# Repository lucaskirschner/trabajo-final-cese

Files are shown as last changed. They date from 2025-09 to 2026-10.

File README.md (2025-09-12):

# \# Trabajo Final CESE – \[Título del Proyecto]

# 

# \## Objetivo

# Breve descripción del sistema (HW+FW) y casos de uso.

# 

# \## Estructura

# \- `hardware/`: Altium, libs, outputs, mecánica.

# \- `firmware/`: drivers, app, tests, build.

# \- `docs/`: requisitos, arquitectura, plan, API.

# 

# \## Cómo compilar (FW)

# Requisitos, comando (CMake/Make), cómo flashear.

# 

# \## Paquetes de fabricación (HW)

# Ubicación y cómo generarlos/validarlos.

# 

# \## Versionado

# Tags `vX.Y.Z-hwA#`. Ver `CHANGELOG.md`.

# 

# \## Licencia

# MIT (o la que definas).

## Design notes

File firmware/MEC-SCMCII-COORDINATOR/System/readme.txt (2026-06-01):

===============================================================================
SYSTEM
===============================================================================

Esta carpeta contiene la arquitectura principal del firmware de la plataforma
embebida. Su organización se basa en una estructura modular por capas, con el
objetivo de facilitar la reutilización de código, el mantenimiento, la
escalabilidad y la adaptación del sistema a distintos escenarios de
automatización industrial.

===============================================================================
APP/
===============================================================================

Contiene la lógica de aplicación del sistema.

En esta capa se implementa el comportamiento funcional de cada tipo de estación
(central o remota), así como también la lógica personalizada desarrollada por
el usuario final. Aquí se integran los distintos servicios y drivers del sistema
para construir la funcionalidad completa de la aplicación.

Esta carpeta puede incluir:

- Aplicación de estación central.
- Aplicación de estación remota.
- Lógica de usuario.
- Máquinas de estados.
- Algoritmos de control.
- Procesamiento de datos.

La capa APP no debería acceder directamente al hardware, sino utilizar las APIs
provistas por las capas inferiores.

===============================================================================
BSP/  (Board Support Package)
===============================================================================

Contiene la capa de abstracción del hardware de la placa.

Su función es desacoplar el firmware de los detalles específicos del hardware
utilizado, encapsulando el acceso a periféricos, GPIOs y recursos físicos de la
plataforma.

Esta carpeta puede incluir:

- Configuración de GPIO.
- Manejo de LEDs.
- Lectura de botones.
- Control de señales de habilitación.
- Mapeo de pines.
- Inicialización básica de periféricos.

El objetivo es permitir la migración del firmware entre distintas revisiones de
hardware o placas minimizando modificaciones en las capas superiores.

===============================================================================
CONFIG/
===============================================================================

Contiene los archivos globales de configuración del sistema.

Aquí se centralizan parámetros de compilación, habilitación de módulos,
selección de funcionalidades y definiciones generales utilizadas por múltiples
capas del firmware.

Esta carpeta puede incluir:

- Configuración de estación central/remota.
- Selección de módulos habilitados.
- Parámetros del sistema.
- Definiciones globales.
- Configuración de hardware.
- Configuración de red y comunicación.

El objetivo es facilitar la parametrización del sistema desde un único punto.

===============================================================================
DRIVERS/
===============================================================================

Contiene los controladores de dispositivos y periféricos externos.

Esta capa encapsula la lógica de comunicación y control de los distintos
componentes conectados al microcontrolador, proporcionando APIs reutilizables e
independientes de la aplicación.

Esta carpeta puede incluir:

- Drivers SPI/I2C/UART.
- Drivers de módulos inalámbricos.
- Drivers Ethernet.
- Drivers de entradas y salidas industriales.
- Drivers de sensores.
- Drivers de RTC.
- Drivers de expansores externos.

La capa DRIVERS debe enfocarse únicamente en el manejo funcional del
dispositivo, evitando incluir lógica de aplicación.

===============================================================================
RTOS/
===============================================================================

Contiene la estructura relacionada con el sistema operativo en tiempo real.

Aquí se organiza la creación y administración de tareas, colas, semáforos,
mutexes, timers y demás recursos asociados al RTOS utilizado por el sistema.

Esta carpeta puede incluir:

- Definición de tareas.
- Inicialización del scheduler.
- Gestión de colas y eventos.
- Configuración de prioridades.
- Temporizadores de software.
- Hooks del RTOS.

El objetivo es mantener centralizada toda la infraestructura de concurrencia y
sincronización del sistema.

===============================================================================
SERVICES/
===============================================================================

Contiene módulos de servicios reutilizables de alto nivel.

Estos módulos implementan funcionalidades generales utilizadas por la aplicación
y los distintos subsistemas del firmware, actuando como intermediarios entre los
drivers y la lógica de aplicación.

Esta carpeta puede incluir:

- Gestión de comunicación.
- Gestión de eventos.
- Servicios de temporización.
- Watchdog lógico.
- Diagnóstico y monitoreo.
- Manejo de errores.
- Registro de eventos y logs.
- Gestión de estados del sistema.

La capa SERVICES permite desacoplar la lógica de aplicación de detalles
específicos de implementación y promueve una arquitectura más modular y
escalable.

===============================================================================

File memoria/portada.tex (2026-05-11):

%----------------------------------------------------------------------------------------
% PORTADA
%----------------------------------------------------------------------------------------
\begin{titlepage}
    % Fondo completo con el PDF que incluye la barra y el logo
    \AddToShipoutPictureBG*{}

    % Contenido principal
    \begin{flushright}
        \setlength{\rightskip}{-2cm} % Ajusta la sangría derecha
        \vspace*{5cm} % Ajustar según la posición vertical deseada

        % Título
        {\fontfamily{phv}\bfseries\fontsize{33pt}{40pt}\selectfont
        Sistema modular para monitoreo y control industrial con comunicación inalámbrica y capacidades de automatización embebida} \\[1.5cm]

        % Autor
        {\fontfamily{phv}\fontsize{20pt}{25pt}\selectfont
        Ing. Lucas Sebastián Kirschner} \\[1cm]

        % Carrera o Maestría (comentar o descomentar la línea correspondiente)
        {\fontfamily{phv}\fontsize{15pt}{20pt}\selectfont
        \textbf{Carrera de Especialización en Sistemas Embebidos}
        % \textbf{Carrera de Especialización en Internet de las Cosas} \\
        % \textbf{Carrera de Especialización en Inteligencia Artificial} \\
        % \textbf{Maestría en Sistemas Embebidos} \\
        % \textbf{Maestría en Internet de las Cosas} \\
        % \textbf{Maestría en Inteligencia Artificial Embebida} \\
        % \textbf{Maestría en Computación de Borde} \\
        % \textbf{Maestría en Inteligencia Artificial} \\
        } \\[2cm]

        % Director
        {\fontfamily{phv}\fontsize{11pt}{15pt}\selectfont
        \textbf{Director:} Mg. Ing. Guillermo Alfredo Fernández (UNaM)} \\[1cm]

        % Jurados
        {\fontfamily{phv}\fontsize{11pt}{15pt}\selectfont
        \textbf{Jurados:}} \\[0.5cm]
        {\fontfamily{phv}\fontsize{11pt}{15pt}\selectfont
        Jurado 1 (pertenencia)} \\ 
        {\fontfamily{phv}\fontsize{11pt}{15pt}\selectfont
        Jurado 2 (pertenencia)} \\ 
        {\fontfamily{phv}\fontsize{11pt}{15pt}\selectfont
        Jurado 3 (pertenencia)} \\[2cm]

        % Fecha y lugar
        {\fontfamily{phv}\itshape\fontsize{10pt}{12pt}\selectfont
        Ciudad de Salto Encantado, octubre de 2026} % Ejemplo: Ciudad de Córdoba, junio de 2025
    \end{flushright}
\end{titlepage}

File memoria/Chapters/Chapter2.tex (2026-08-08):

\chapter{Introducción específica}
\label{Chapter2}

En este capítulo se describen las principales plataformas de hardware, componentes externos, capas de software y protocolos de comunicación utilizados durante el desarrollo del trabajo. Asimismo, se presentan las tecnologías de terceros empleadas para la implementación de las funciones de adquisición, procesamiento y comunicación del sistema.

%----------------------------------------------------------------------------------------

\section{Plataforma de hardware}

Tanto la estación central como las estaciones remotas del sistema utilizan el microcontrolador STM32H563RI de STMicroelectronics, perteneciente a la familia STM32H5 \cite{STM32H563,STMicroelectronics,STM32H5}. Esta decisión permitió uniformar la arquitectura de hardware y simplificar el desarrollo y mantenimiento del firmware. Además, facilitó la reutilización de controladores, configuraciones de periféricos y capas de abstracción de hardware entre ambos tipos de nodos.

El STM32H563RI se basa en una arquitectura ARM Cortex-M33 de 32 bits \cite{CortexM33}, orientada a sistemas embebidos de alto rendimiento y plataformas conectadas. El núcleo incorpora una unidad de punto flotante FPU (\textit{Floating Point Unit}, unidad de punto flotante), extensiones DSP (\textit{Digital Signal Processing}, procesamiento digital de señales) y mecanismos de seguridad basados en TrustZone \cite{STM32H5,STM32H563_RefManual}, adecuados para aplicaciones industriales e IoT.

El microcontrolador dispone de memoria Flash integrada y memoria SRAM (\textit{Static Random Access Memory}, memoria estática de acceso aleatorio) interna, además de una amplia variedad de periféricos de comunicación y control \cite{STM32H563}. Entre los periféricos utilizados durante el desarrollo se encuentran interfaces SPI (\textit{Serial Peripheral Interface}, interfaz periférica serie), UART (\textit{Universal Asynchronous Receiver-Transmitter}, transmisor-receptor asíncrono universal) y Ethernet MAC (\textit{Media Access Control}, control de acceso al medio).

La selección de este microcontrolador también se fundamentó en la disponibilidad de herramientas de desarrollo y middleware provistos por STMicroelectronics, incluido STM32CubeIDE \cite{stm32cubeide}, bibliotecas HAL (\textit{Hardware Abstraction Layer}, capa de abstracción de hardware) \cite{hal} y soporte para sistemas operativos de tiempo real como FreeRTOS \cite{freertos}. Estas herramientas simplificaron significativamente el desarrollo, depuración y mantenimiento del firmware del sistema.

%----------------------------------------------------------------------------------------

\section{Componentes y módulos externos}

Complementariamente a la plataforma de procesamiento basada en el STM32H\-563RI, el sistema incorpora diversos circuitos integrados y módulos externos destinados a la adquisición de señales industriales, el control de entradas y salidas, las comunicaciones cableadas e inalámbricas, la alimentación del sistema y la validación del firmware durante las etapas de desarrollo. A continuación, se describen los componentes más relevantes utilizados en el presente trabajo.

\subsection{SCLT3-8BT8}

El SCLT3-8BT8 de STMicroelectronics es una interfaz de entradas digitales industriales de ocho canales con transferencia serializada de estados mediante interfaz SPI \cite{sclt38bt8}. El dispositivo está orientado a aplicaciones de automatización industrial y PLC. Además, proporciona adaptación y protección para señales de 24 V provenientes de sensores y dispositivos industriales.

El circuito incorpora protección contra sobretensiones y compatibilidad con estándares industriales de inmunidad electromagnética, incluida IEC61000-4-2, IEC\-61000-4-4 e IEC61000-4-5. Además, dispone de indicadores de estado integrados y mecanismos de diagnóstico para detección de fallas en las entradas.

\subsection{VNI8200XP-32}

El VNI8200XP-32 de STMicroelectronics es un controlador de salidas digitales industriales de ocho canales basado en transistores MOSFET (\textit{Metal-Oxide-Semicon\-ductor Field-Effect Transistor}, transistor de efecto de campo metal-óxido-semicon\-ductor) de tipo \textit{high-side} \cite{vni8200xp32}. El dispositivo permite accionar cargas industriales de 24 V mediante una interfaz SPI o paralelo configurable.

El componente incorpora funciones de protección y diagnóstico, incluyendo protección térmica, limitación de corriente, detección de sobrecorriente, monitoreo de alimentación y señalización de fallas. También dispone de mecanismos específicos frente a condiciones de cortocircuito y sobretemperatura, características relevantes en aplicaciones industriales.

\subsection{SN65HVD82}

El SN65HVD82 de Texas Instruments es un transceptor RS-485 (\textit{Recommended Standard 485}) diseñado para comunicaciones industriales robustas \cite{sn65hvd82}. El dispositivo opera con alimentación de 5 V y proporciona transmisión diferencial compatible con buses multipunto de larga distancia.

El componente incorpora protección ESD (\textit{Electrostatic Discharge}, descarga electrostática) conforme a normas IEC orientadas a aplicaciones industriales y permite operación en entornos con elevado nivel de ruido electromagnético. Además, soporta altas velocidades de transmisión y presenta bajo consumo energético.

\subsection{MRF24J40}

El MRF24J40 de Microchip es un transceptor inalámbrico compatible con el estándar IEEE 802.15.4 \cite{mrf24j40}. El dispositivo opera en la banda ISM (\textit{Industrial, Scientific and Medical}, industrial, científica y médica) de 2.4 GHz y está orientado a aplicaciones de redes inalámbricas de bajo consumo.

El componente incorpora las capas PHY y MAC, además de mecanismos de cifrado AES-128 (\textit{Advanced Encryption Standard}, estándar de cifrado avanzado). La comunicación con el microcontrolador se realiza mediante interfaz SPI.

\subsection{LAN8742A}

El LAN8742A de Microchip es un transceptor Ethernet PHY compatible con Ethernet 10BASE-T y 100BASE-TX \cite{lan8742a}. El dispositivo se comunica con el microcontrolador mediante interfaz RMII (\textit{Reduced Media Independent Interface}, interfaz independiente del medio reducida), lo que permite implementar conectividad Ethernet de bajo número de pines.

El componente incorpora soporte para autonegociación, detección automática de polaridad y tecnología HP Auto-MDIX (\textit{Automatic Medium-Dependent Interface Crossover}, cruce automático de interfaz dependiente del medio), característica que permite utilizar cables directos o cruzados.

\subsection{Convertidor CC/CC aislado de 5 V}

El módulo 1769405341 de Würth Elektronik \cite{wurth1769405341} es un convertidor CC/CC aislado empleado para generar la alimentación de 5 V destinada a los circuitos que requieren aislamiento galvánico respecto de la alimentación principal del sistema. El dispositivo incorpora un aislamiento de 1 kV entre entrada y salida y proporciona una potencia de hasta 2 W, características que permiten alimentar las interfaces aisladas manteniendo la separación eléctrica entre ambos dominios de potencia.

\subsection{Kits de desarrollo y evaluación}

Durante las etapas iniciales del proyecto se utilizaron placas STM32 NUCLEO-H563ZI \cite{nucleoh563}, basadas en el microcontrolador STM32H563ZI. Estas placas permitieron realizar pruebas funcionales y tareas de depuración temprana antes del desarrollo del hardware definitivo.

Asimismo, se empleó la placa de expansión X-NUCLEO-PLC01A1 \cite{nucleoplc}, orientada a aplicaciones PLC industriales. Esta placa integra los dispositivos SCLT3-8BT8 \cite{sclt38bt8} y VNI8200XP-32 \cite{vni8200xp32}, que proporcionan entradas y salidas industriales de 24 V manejadas mediante SPI. Su utilización permitió validar la arquitectura de firmware y los controladores desarrollados para las interfaces industriales utilizadas posteriormente en el diseño final.

%----------------------------------------------------------------------------------------

\section{Sistema operativo y middleware}

El desarrollo del firmware del sistema se realizó utilizando distintas capas de software orientadas a facilitar la abstracción del hardware, la administración de tareas concurrentes y la implementación de protocolos de comunicación.

\subsection{FreeRTOS}

FreeRTOS es un sistema operativo de tiempo real ampliamente utilizado en sistemas embebidos \cite{freertos}. El sistema proporciona mecanismos de planificación multitarea basados en prioridades, sincronización mediante semáforos y mutex, comunicación entre tareas y administración de temporizadores de software.

En el sistema desarrollado, FreeRTOS actuó como núcleo del sistema operativo, mientras que la aplicación utilizó la interfaz estandarizada CMSIS-RTOS2 (\textit{Cortex Microcontroller Software Interface Standard for Real-Time Operating Systems}, estándar de interfaz de software para microcontroladores Cortex para sistemas operativos de tiempo real) para acceder a sus servicios.

\subsection{CMSIS-RTOS2}

El desarrollo de la aplicación en tiempo real se realizó mediante la interfaz CMSIS-RTOS2, especificada por Arm \cite{cmsisrtos2}. Esta interfaz define una API estandarizada para sistemas operativos de tiempo real, independiente del núcleo RTOS utilizado.

CMSIS-RTOS2 proporciona mecanismos para la creación y administración de tareas, sincronización mediante semáforos y mutex, comunicación entre tareas, temporizadores y control del tiempo de ejecución. Al definir una interfaz común, permite desacoplar la aplicación del sistema operativo subyacente y facilita la reutilización del código sobre diferentes implementaciones compatibles, como FreeRTOS, CMSIS-RTX y otros sistemas operativos de tiempo real.

En el sistema desarrollado, CMSIS-RTOS2 se utilizó como capa de abstracción entre la aplicación y FreeRTOS. Esta arquitectura permitió desarrollar el firmware utilizando una API estandarizada, reduciendo la dependencia de funciones específicas del RTOS y favoreciendo la portabilidad y el mantenimiento del software.

\subsection{HAL}

Para el acceso y configuración de los periféricos del microcontrolador se utilizaron las bibliotecas HAL provistas por STMicroelectronics \cite{hal}.

La capa HAL proporciona funciones de alto nivel para el manejo de los periféricos internos del microcontrolador, incluyendo interfaces SPI, UART, Ethernet y temporizadores. Esta capa simplifica el desarrollo del firmware mediante una interfaz uniforme e independiente de los registros específicos del hardware, favoreciendo la portabilidad y el mantenimiento del software.

\subsection{lwIP}

Para la implementación de conectividad Ethernet y protocolos TCP/IP (\textit{Transmission Control Protocol/Internet Protocol}, protocolo de control de transmisión/protocolo de internet) se utilizó el \textit{stack} lwIP (\textit{Lightweight IP}) \cite{tcpip,lwip}.

lwIP es una implementación liviana del protocolo TCP/IP \cite{tcpip} orientada a sistemas embebidos con recursos limitados. El \textit{stack} incorpora soporte para protocolos IPv4, TCP, UDP (\textit{User Datagram Protocol}, protocolo de datagrama de usuario), ICMP (\textit{Internet Control Message Protocol}, protocolo de mensajes de control de internet), DHCP (\textit{Dynamic Host Configuration Protocol}, protocolo de configuración dinámica de host) y ARP (\textit{Address Resolution Protocol}, protocolo de resolución de direcciones).

En el sistema desarrollado, lwIP fue integrado junto con FreeRTOS y el periférico Ethernet del STM32H563RI. Esta integración permitió implementar comunicación Ethernet para supervisión, configuración y transmisión de datos mediante redes TCP/IP.

\section{Protocolos e interfaces de comunicación}

El sistema desarrollado utiliza distintas interfaces y protocolos de comunicación orientados a la adquisición de datos, control de periféricos, conectividad Ethernet y depuración del firmware. La selección de cada interfaz se realizó en función de los requerimientos de velocidad, complejidad de implementación, robustez y compatibilidad con los dispositivos externos utilizados en el proyecto.

\subsection{SPI}

La interfaz SPI fue utilizada para la comunicación entre el microcontrolador y distintos circuitos integrados externos, incluyendo las interfaces industriales SCLT3-8BT8 \cite{sclt38bt8} y VNI8200XP-32 \cite{vni8200xp32}, así como también el transceptor inalámbrico MRF\-24J40 \cite{mrf24j40}.

SPI es un protocolo de comunicación serial síncrono basado en una arquitectura maestro-esclavo, caracterizado por su elevada velocidad de transferencia y baja complejidad de implementación. La interfaz utiliza líneas dedicadas de transmisión, recepción y señal de reloj, además de señales independientes de selección de dispositivo.

\subsection{UART y RS-485}

La interfaz UART fue utilizada junto con el transceptor SN65HVD82 \cite{sn65hvd82} para implementar comunicación RS-485 \cite{rs485}.

UART permite establecer comunicaciones seriales asíncronas mediante transmisión y recepción de datos sin necesidad de señal de reloj compartida. En conjunto con RS-485, posibilita implementar enlaces diferenciales robustos, adecuados para entornos industriales con elevado nivel de ruido electromagnético y largas distancias de cableado.

\subsection{Ethernet y RMII}

La conectividad Ethernet del sistema se implementó mediante el periférico Ethernet MAC integrado en el microcontrolador STM32H563RI \cite{STM32H563_RefManual} y el transceptor Ethernet PHY LAN8742A \cite{lan8742a}.

La comunicación entre el microcontrolador y el PHY se realizó mediante la interfaz RMII \cite{rmii}, utilizada para transmisión y recepción de datos Ethernet con bajo número de pines.

La capa física Ethernet permite establecer comunicación 10BASE-T y 100BASE-TX sobre medio cableado de par trenzado. Esto facilita la integración con redes Ethernet industriales y servicios basados en TCP/IP.

\subsection{IEEE 802.15.4}

La comunicación inalámbrica entre la estación central y las estaciones remotas se basa en el estándar IEEE 802.15.4 \cite{ieee_standard}. Este estándar define la capa física PHY y la subcapa de control de acceso al medio MAC para redes inalámbricas personales de baja velocidad. Está orientado a enlaces de corto alcance que requieren bajo consumo energético, reducida complejidad y bajo costo de implementación.

Para el enlace desarrollado se utiliza la banda ISM de 2,4 GHz, en la que el estándar admite una velocidad de transmisión de hasta 250 kbps. La capa PHY establece las características de transmisión y recepción por radiofrecuencia, mientras que la subcapa MAC proporciona funciones de acceso al canal, direccionamiento, validación de tramas y confirmación de recepción. Estas características resultan adecuadas para el intercambio de información de monitoreo y control entre los nodos del sistema.

\subsection{GPIO}

Las interfaces GPIO (\textit{General Purpose Input/Output}, entrada/salida de propósito general) fueron utilizadas para el manejo de señales digitales de control, monitoreo de estados y accionamiento de indicadores luminosos.

Estas señales incluyen líneas de habilitación de periféricos, señales de interrupción, selección de dispositivos SPI, monitoreo de estados de alimentación y control de LEDs indicadores presentes en la placa.

\subsection{SWD}

La programación y depuración del microcontrolador se realizó mediante la interfaz SWD (\textit{Serial Wire Debug}) \cite{swi}, utilizada por las herramientas de desarrollo STMicroelectronics.

SWD constituye una interfaz de depuración derivada de JTAG (\textit{Joint Test Action Group}) \cite{jtag}. Esta interfaz reduce la cantidad de señales requeridas y conserva capacidades de programación, ejecución paso a paso, lectura de memoria y monitoreo interno del sistema embebido.

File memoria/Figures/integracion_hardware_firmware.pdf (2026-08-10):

Entradas digitales | Salidas digitales

Interfaz RS485

Interfaz de radiofrecuencia

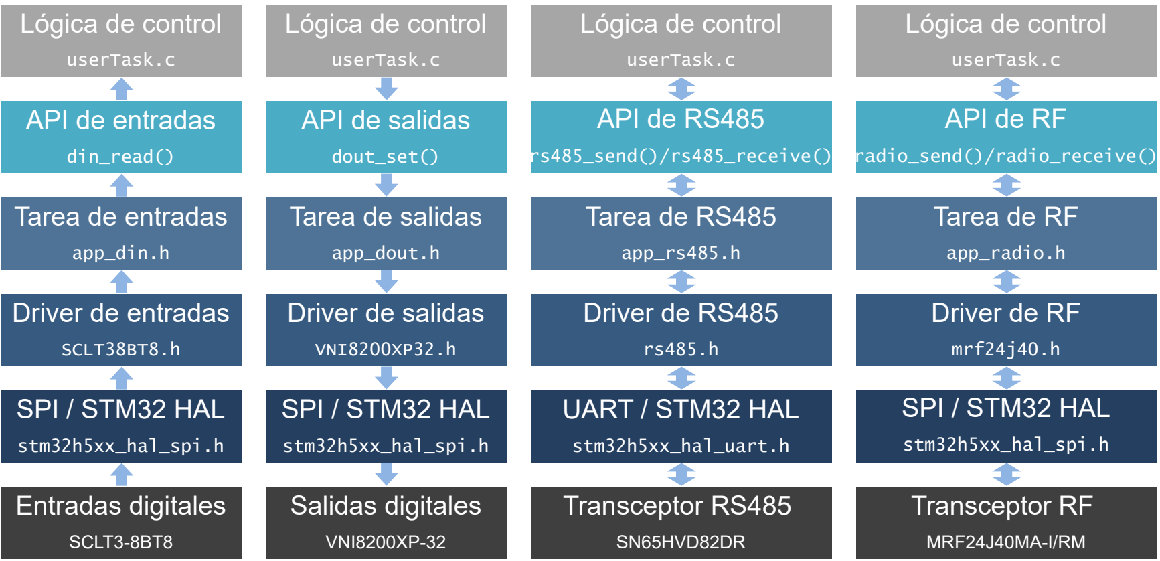
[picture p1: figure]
Entradas digitales; SCLT3-8BT8; SPI / STM32 HAL; stm32h5xx_hal_spi.h; Driver de entradas; SCLT38BT8.h; Lógica de control; userTask.c; API de entradas; din_read(); Tarea de entradas; app_din.h; Salidas digitales; VNI8200XP-32; Driver de salidas; VNI8200XP32.h; API de salidas; dout_set(); Tarea de salidas; app_dout.h; Transceptor RS485; SN65HVD82DR; UART / STM32 HAL; stm32h5xx_hal_uart.h; Driver de RS485; API de RS485; rs485_send()/rs485_receive(); Tarea de RS485; app_rs485.h; Transceptor RF; MRF24J40MA-I/RM; Driver de RF; mrf24j40.h; API de RF; radio_send()/radio_receive(); Tarea de RF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

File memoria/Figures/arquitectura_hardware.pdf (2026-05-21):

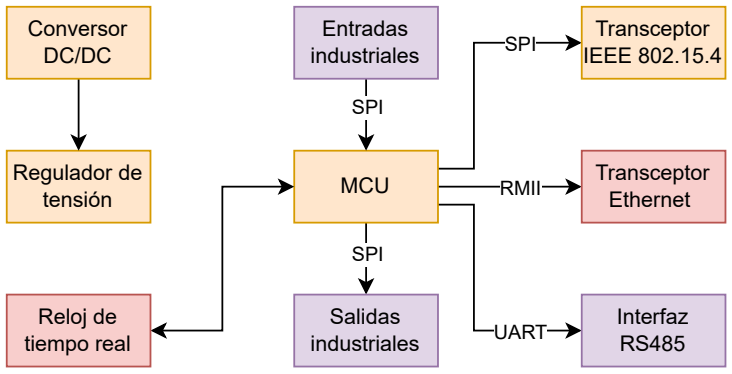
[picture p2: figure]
SPI; RMII; UART; MCU; Transceptor; Ethernet; Transceptor IEEE 802.15.4; Interfaz RS485; Salidas industriales; Entradas industriales; Regulador de tensión; Conversor DC/DC; Reloj de tiempo real

Componentes de estaciones centrales y remotas

Componentes de estaciones remotas

Componentes de estaciones centrales

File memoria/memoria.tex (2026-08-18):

%----------------------------------------------------------------------------------------
% Preambulo y Configuración
%----------------------------------------------------------------------------------------

\documentclass[
    11pt,
    spanish,
    singlespacing,
    parskip,
    headsepline,
    bookmarks=true,
    unicode=true,
    pdftoolbar=true,
    pdfmenubar=true,
    pdffitwindow=false,
    colorlinks=true,
    linkcolor=blue,
    citecolor=blue,
    urlcolor=blue
]{MastersDoctoralThesis}

\usepackage[utf8]{inputenc} % Codificación de entrada UTF-8
\usepackage[T1]{fontenc}    % Codificación de salida para caracteres especiales
\usepackage{graphicx}       % Manejo de gráficos
\usepackage{eso-pic}        % Permite agregar fondos
\usepackage{hyperref}       % Manejo de hipervínculos y marcadores
\usepackage{float}          % Control preciso de la posición de figuras y tablas

% Redefinición de caracteres problemáticos en marcadores
\hypersetup{
    pdftitle={Memoria CESE},
    pdfauthor={Lucas S. Kirschner},
    pdfkeywords={Sistemas Embebidos},
    pdfstartview={FitH},
    unicode=true,
    colorlinks=true,
    linkcolor=blue,
    citecolor=blue,
    urlcolor=blue
}

\pdfstringdefDisableCommands{%
  \def\texttt#1{#1}%
  \def\textbf#1{#1}%
  \def\textit#1{#1}%
  \def\"{\"}%
  \def\~{~}%
  \def\'{'}%
  \def\^{}%
  \def\textunderscore{\_} % Manejo del subrayado en marcadores
}

% Definir comandos requeridos por la clase
\newcommand{\degreename}{Carrera de Especialización en Sistemas Embebidos} % Cambia según tu título
\newcommand{\univname}{Universidad Nacional de Misiones} % Cambia según tu universidad
\newcommand{\keywordnames}{Palabras clave:}
%----------------------------------------------------------------------------------------
% Documento Principal
%----------------------------------------------------------------------------------------

\begin{document}

% Configuración de la portada
\posgrado{Carrera / Maestría}
\keywords{Sistemas Embebidos, Internet de las Cosas, Inteligencia Artificial}

% Incluir la portada desde un archivo separado
\include{portada}

% Configuración del contenido preliminar
\frontmatter % Usar numeración romana para las páginas preliminares
\pagestyle{plain} % Estilo de encabezado simple

%----------------------------------------------------------------------------------------
% Resumen
%----------------------------------------------------------------------------------------

\begin{abstract}
\addchaptertocentry{\abstractname} % Agregar resumen al índice
Este documento presenta el desarrollo de un sistema modular para monitoreo y control industrial con comunicación inalámbrica y capacidades de automatización embebida. La solución propuesta permite adquirir datos de campo, controlar actuadores y facilitar la integración de estaciones distribuidas en entornos donde las soluciones cableadas resultan poco prácticas o costosas.

Su desarrollo requirió conocimientos en sistemas embebidos, diseño de hardware electrónico, desarrollo de firmware, sistemas operativos en tiempo real, protocolos de comunicación industrial, redes inalámbricas y diseño de software modular.
\end{abstract}

%----------------------------------------------------------------------------------------
% Agradecimientos
%----------------------------------------------------------------------------------------

\begin{acknowledgements}
\vspace{1.5cm}
Esta sección es para agradecimientos personales y es totalmente \textbf{OPCIONAL}.
\end{acknowledgements}

%----------------------------------------------------------------------------------------
% Índice
%----------------------------------------------------------------------------------------

\tableofcontents
\listoffigures
\listoftables

%----------------------------------------------------------------------------------------
% Dedicatoria
%----------------------------------------------------------------------------------------

\dedicatory{\textbf{Dedicado a... [OPCIONAL]}}

%----------------------------------------------------------------------------------------
% Capítulos
%----------------------------------------------------------------------------------------

\mainmatter % Iniciar numeración numérica para el contenido principal
\pagestyle{thesis} % Estilo de encabezado de tesis

% Incluir capítulos desde archivos separados
\include{Chapters/Chapter1}
\include{Chapters/Chapter2}
\include{Chapters/Chapter3}
\include{Chapters/Chapter4}
%\include{Chapters/Chapter5}

%----------------------------------------------------------------------------------------
% Apéndices
%----------------------------------------------------------------------------------------

\appendix

% Incluir apéndices desde archivos separados si es necesario
%\include{Appendices/AppendixA}

%----------------------------------------------------------------------------------------
% Bibliografía
%----------------------------------------------------------------------------------------

\renewcommand{\bibname}{Bibliografía} % Para asegurarte de que el título sea correcto
\phantomsection % Necesario para que el enlace del marcador sea correcto

\printbibliography[heading=bibintoc]

\end{document}

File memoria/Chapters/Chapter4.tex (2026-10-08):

\chapter{Ensayos y resultados}
\label{Chapter4}

En este capítulo se presentan los ensayos realizados para verificar el funcionamiento del hardware y del firmware desarrollados, así como su integración en el sistema completo. Las pruebas comprenden la evaluación de los principales bloques de hardware, las funciones implementadas en el firmware y la comunicación entre la estación central y las estaciones remotas. Finalmente, se analizan los resultados obtenidos y los principales desvíos y limitaciones identificados durante la validación.

%----------------------------------------------------------------------------------------
\section{Plan de ensayos}

La validación del sistema se realizó siguiendo una metodología incremental, que comenzó con la verificación individual de los distintos bloques de hardware y firmware y continuó con ensayos de integración entre ambos niveles. Finalmente, se realizaron pruebas sobre el sistema completo, orientadas a comprobar el intercambio de información y la ejecución coordinada de las funciones implementadas entre la estación central y las estaciones remotas.

Para cada ensayo se establecieron las condiciones iniciales, la configuración utilizada, el procedimiento de prueba y los resultados esperados. Las pruebas de hardware se orientaron principalmente a verificar las etapas de alimentación, las entradas y salidas digitales y las interfaces de comunicación. Los ensayos de firmware contemplaron la comprobación de los controladores y servicios desarrollados, la ejecución de las tareas de FreeRTOS y la temporización de las operaciones relevantes. Por último, las pruebas de integración evaluaron el funcionamiento conjunto de estos elementos mediante operaciones representativas del sistema.

Los ensayos se realizaron en condiciones controladas de laboratorio mediante el instrumental y las herramientas de desarrollo indicados en la tabla \ref{tab:instrumental_ensayos}. La figura \ref{fig:banco_ensayos} muestra el banco de trabajo utilizado. Los criterios de aceptación se establecieron a partir de los requerimientos funcionales del sistema y de las especificaciones de los componentes utilizados. Según el tipo de ensayo, se consideraron los niveles de tensión y corriente, las características temporales de las señales, la correcta ejecución de las funciones y el intercambio de información entre los distintos módulos.

\begin{table}[H]
	\centering
	\caption[Instrumental y herramientas utilizados en los ensayos]
	{Instrumental y herramientas utilizados para la realización de los ensayos.}
	\begin{tabular}{l l}
		\toprule
		\textbf{Instrumento o herramienta} & \textbf{Utilización} \\
		\midrule
		Fuente regulada de laboratorio
		& Alimentación del sistema \\
		
		Multímetro digital
		& Medición de tensión y corriente \\
		
		Osciloscopio digital
		& Análisis temporal de señales \\
		
		Analizador lógico USB de 8 canales
		& Análisis de señales digitales \\
		
		Generador de señales digitales
		& Estimulación de entradas \\
		
		STLINK-V3MINIE
		& Programación y depuración \\
		
		STM32CubeIDE
		& Depuración del firmware \\
		
		Vistas de FreeRTOS
		& Supervisión de objetos del RTOS \\
		
		Interfaz SWO
		& Registro de eventos y variables \\
		
		Contador de ciclos DWT
		& Medición de tiempos de ejecución \\
		\bottomrule
	\end{tabular}
	\label{tab:instrumental_ensayos}
\end{table}

\begin{figure}[H]
	\centering
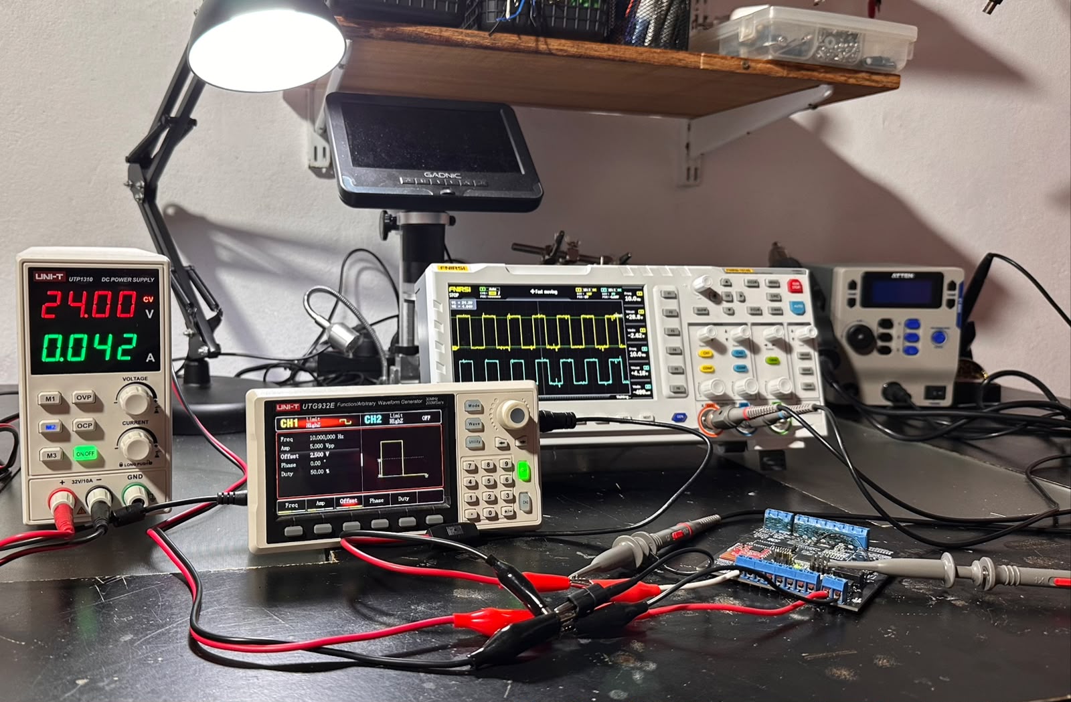
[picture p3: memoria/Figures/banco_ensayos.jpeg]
	
	\caption{Banco de trabajo e instrumental utilizado para la realización de los ensayos.}
	\label{fig:banco_ensayos}
\end{figure}

%----------------------------------------------------------------------------------------
\section{Ensayos de hardware}

En esta sección se presentan los ensayos realizados sobre los principales bloques de hardware del sistema. Las pruebas comprenden la verificación de las tensiones de alimentación y el consumo de corriente, el funcionamiento de las entradas y salidas digitales y las señales asociadas a las interfaces de comunicación. Para cada ensayo se indican las condiciones de medición y los resultados obtenidos mediante el instrumental presentado en la sección anterior.

%----------------------------------------------------------------------------------------
\subsection{Ensayo de las etapas de alimentación y consumo}

Como primera etapa de validación del hardware, se verificaron las principales tensiones de alimentación y el consumo de corriente de la placa. El sistema se alimentó con 24 V y se midieron, mediante un multímetro digital, las líneas de 5 V y 3,3 V, junto con la corriente consumida desde la alimentación principal. Esta última medición se realizó con la placa en estado de reposo, sin cargas externas conectadas ni operaciones activas de adquisición, actuación o comunicación. Los valores obtenidos se presentan en la tabla \ref{tab:alimentacion_consumo}.

\begin{table}[h]
	\centering
	\caption[Mediciones de alimentación y consumo]{Mediciones de las tensiones de alimentación y del consumo de corriente de la placa.}
	\begin{tabular}{l c c}
		\toprule
		\textbf{Magnitud} & \textbf{Nominal} & \textbf{Medido} \\
		\midrule
		Alimentación de entrada & 24 V  & 24 V \\
		Alimentación de 5 V     & 5 V   & 5,02 V \\
		Alimentación de 3,3 V   & 3,3 V & 3,31 V \\
		Consumo a 24 V          & --    & 21 mA \\
		\bottomrule
	\end{tabular}
	\label{tab:alimentacion_consumo}
\end{table}

Los resultados obtenidos permitieron verificar el correcto funcionamiento de las etapas de alimentación en las condiciones consideradas. Las líneas de 5 V y 3,3 V presentaron valores próximos a sus niveles nominales, mientras que el consumo base medido sobre la alimentación de entrada de 24 V fue de 21 mA.

%----------------------------------------------------------------------------------------
\subsection{Ensayo de la etapa de entradas digitales}

Para verificar el funcionamiento de la etapa de entradas digitales, se aplicó sobre el canal 1 una señal cuadrada de 10 Hz con niveles de 0 V y 24 V. El microcontrolador realizó periódicamente la lectura mediante la interfaz SPI del SCLT3-8BT8 dentro de un \textit{superloop} y replicó el estado detectado sobre el pin GPIO0 de la placa.

La figura \ref{fig:ensayos_io_digitales}\subref{fig:ensayo_entradas_digitales} muestra las señales registradas con el osciloscopio. El canal 1 (amarillo) corresponde a la señal aplicada a la entrada digital, mientras que el canal 2 (celeste) corresponde al estado obtenido en GPIO0. La correspondencia entre ambas formas de onda permitió comprobar la detección de los niveles de 0 V y 24 V, su adquisición mediante SPI y su posterior procesamiento por el microcontrolador.

%----------------------------------------------------------------------------------------
\subsection{Ensayo de la etapa de salidas digitales}

Para verificar el funcionamiento de la etapa de salidas digitales, se configuró la conmutación periódica del canal 1 a una frecuencia de 1 Hz. El microcontrolador actualizó su estado mediante la interfaz SPI del VNI8200XP-32 dentro de un \textit{superloop} y replicó simultáneamente el estado lógico comandado sobre el pin GPIO0 de la placa.

La figura \ref{fig:ensayos_io_digitales}\subref{fig:ensayo_salidas_digitales} muestra las señales registradas con el osciloscopio. El canal 1 (amarillo) corresponde a la salida industrial de 24 V, mientras que el canal 2 (celeste) corresponde a la señal obtenida en GPIO0. La correspondencia entre ambas formas de onda permitió comprobar la transmisión del estado mediante SPI y la conmutación de la salida industrial de acuerdo con el comando establecido por el microcontrolador.

\begin{figure}[!htpb]
	\centering
	\begin{subfigure}[b]{0.48\textwidth}
		\centering
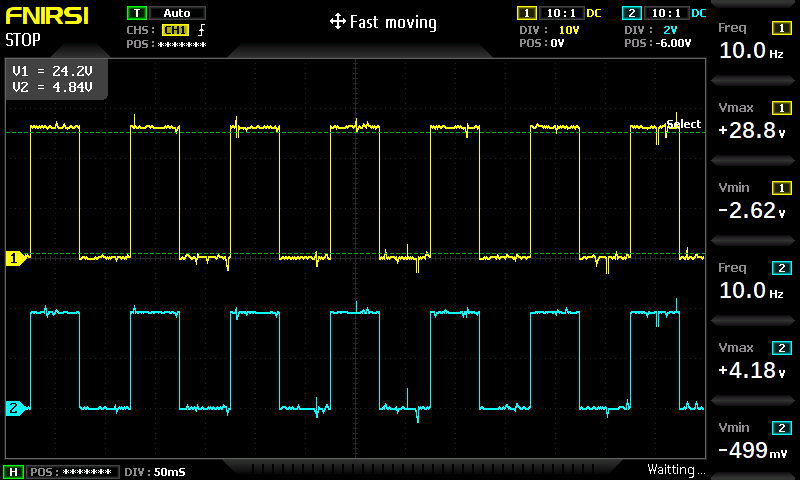
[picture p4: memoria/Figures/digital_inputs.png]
		
		\caption{Ensayo de la entrada digital.}
		\label{fig:ensayo_entradas_digitales}
	\end{subfigure}
	\hfill
	\begin{subfigure}[b]{0.48\textwidth}
		\centering
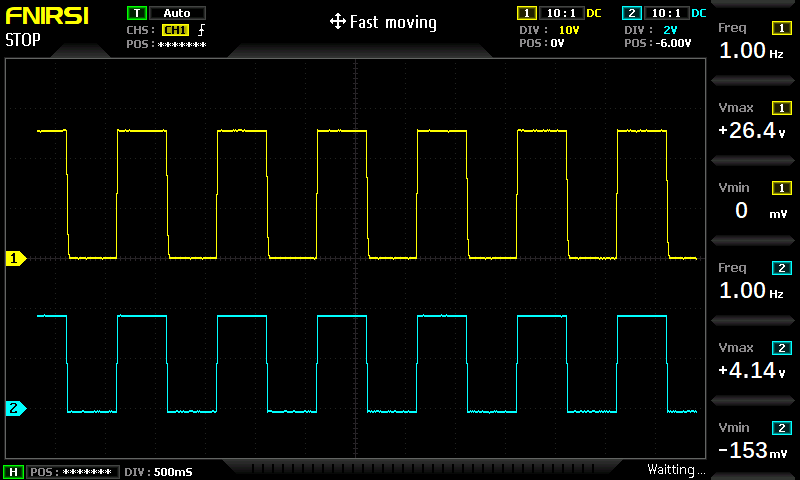
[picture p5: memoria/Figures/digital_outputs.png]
		
		\caption{Ensayo de la salida digital.}
		\label{fig:ensayo_salidas_digitales}
	\end{subfigure}
	\caption[Ensayos de las entradas y salidas digitales]{Señales registradas durante los ensayos de las etapas de entradas y salidas digitales.}
	\label{fig:ensayos_io_digitales}
\end{figure}

%----------------------------------------------------------------------------------------
\subsection{Ensayo de la interfaz RS485}

Para verificar el funcionamiento de la interfaz RS485, se conectó la placa a una computadora mediante un adaptador USB--RS485 y se configuró la comunicación a 115200 bit/s, con 8 bits de datos, sin paridad y un bit de parada. Desde RealTerm se transmitió la trama de 8 bytes \texttt{AA 55 01 02 03 04 12 34} para comprobar el intercambio de información binaria sin alteraciones.

El microcontrolador recibió la trama mediante UART7, verificó su correspondencia con la secuencia esperada y registró el resultado mediante SWO. A continuación, el transceptor RS485 se conmutó a modo de transmisión y retransmitió la misma trama hacia la computadora, retornando luego al modo de recepción.

La figura \ref{fig:ensayo_rs485} muestra los resultados obtenidos. En la figura \ref{fig:rs485_realterm} se observa la trama retransmitida en RealTerm y, en la figura \ref{fig:rs485_swo}, el registro de su recepción, validación y retransmisión mediante SWO. La coincidencia entre ambas tramas permitió comprobar la comunicación bidireccional y la correcta conmutación entre los modos de recepción y transmisión.

\begin{figure}[ht]
	\centering
	\begin{subfigure}[b]{0.9\textwidth}
		\centering
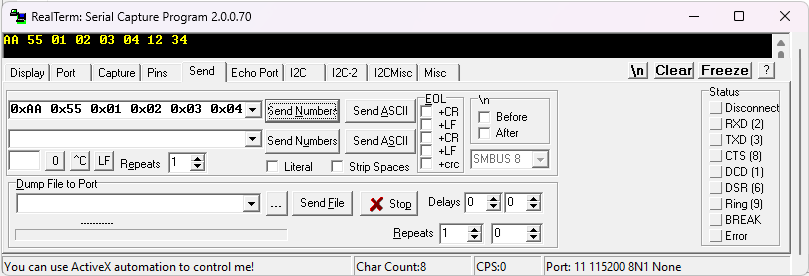
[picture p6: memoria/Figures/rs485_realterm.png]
		
		\caption{Trama retransmitida visualizada mediante RealTerm.}
		\label{fig:rs485_realterm}
	\end{subfigure}
	
	\vspace{0.3cm}
	
	\begin{subfigure}[b]{0.9\textwidth}
		\centering
		
		\caption{Registro de recepción, validación y retransmisión mediante SWO.}
		\label{fig:rs485_swo}
	\end{subfigure}
	
	\caption[Ensayo de la interfaz RS485]{Resultados del ensayo de transmisión y recepción mediante la interfaz RS485.}
	\label{fig:ensayo_rs485}
\end{figure}

%----------------------------------------------------------------------------------------
\subsection{Ensayo de la interfaz inalámbrica}

Para verificar el funcionamiento de la interfaz inalámbrica, se realizó una prueba de comunicación punto a punto entre dos placas equipadas con transceptores MRF24J40. Una de ellas se configuró como dispositivo con dirección corta \texttt{0x0002}, mientras que la segunda se configuró como coordinador con dirección \texttt{0x0001}. Ambos nodos utilizaron el identificador de red PAN \texttt{0x1234}.

Durante el ensayo, el dispositivo transmitió la trama de prueba de 12 bytes \texttt{41 88 01 34 12 01 00 02 00 01 02 03}. La transmisión se inició mediante una interrupción externa asociada al pulsador de usuario y se realizó sin solicitud de ACK. La finalización de la transmisión fue detectada mediante la interrupción generada por el MRF24J40 y registrada mediante SWO. En el coordinador, la recepción generó una nueva interrupción del transceptor, tras la cual se leyó la FIFO y se registraron la longitud y el contenido de la trama recibida.

La figura \ref{fig:ensayo_radio} muestra los registros obtenidos durante el ensayo. En la figura \ref{fig:radio_tx_swo} se observa la trama enviada por el dispositivo y la finalización de la transmisión, mientras que en la figura \ref{fig:radio_rx_swo} se presenta la trama recibida por el coordinador. La coincidencia entre los 12 bytes transmitidos y recibidos permitió comprobar la correcta comunicación inalámbrica entre ambos nodos, así como el funcionamiento de la interfaz SPI y de las interrupciones utilizadas para gestionar el MRF24J40.

\begin{figure}[!htpb]
	\centering
	\begin{subfigure}[b]{0.9\textwidth}
		\centering
		
		\caption{Registro de la transmisión en el nodo dispositivo mediante SWO.}
		\label{fig:radio_tx_swo}
	\end{subfigure}
	
	\vspace{0.5cm}
	
	\begin{subfigure}[b]{0.9\textwidth}
		\centering
		
		\caption{Registro de la recepción en el nodo coordinador mediante SWO.}
		\label{fig:radio_rx_swo}
	\end{subfigure}
	
	\caption[Ensayo de la interfaz inalámbrica]{Registros obtenidos durante el ensayo de comunicación punto a punto mediante IEEE 802.15.4.}
	\label{fig:ensayo_radio}
\end{figure}

%----------------------------------------------------------------------------------------
\section{Ensayos de firmware}

En esta sección se presentan los ensayos realizados para verificar el funcionamiento de los controladores de firmware y caracterizar los tiempos de ejecución de las operaciones relevantes del sistema. Las pruebas comprenden la validación unitaria de los controladores y la evaluación temporal de las operaciones de adquisición, actuación y comunicación inalámbrica.

%----------------------------------------------------------------------------------------
\subsection{Pruebas unitarias}

% PENDIENTE:
% Incorporar la metodología y los resultados de las pruebas unitarias
% realizadas mediante Ceedling, Unity y CMock.
% Incluir la tabla de resultados de los controladores:
% SCLT3-8BT8, VNI8200XP-32, RS485 y MRF24J40.

%----------------------------------------------------------------------------------------
\subsection{Evaluación temporal del firmware}

Para caracterizar el desempeño temporal del sistema, se realizaron mediciones sobre las operaciones de adquisición de entradas digitales, actualización de salidas digitales y comunicación inalámbrica. Los ensayos se efectuaron sobre el hardware de desarrollo, utilizando el contador de ciclos DWT para las operaciones locales y un osciloscopio digital para determinar la latencia de comunicación entre dispositivos.

%----------------------------------------------------------------------------------------
\subsubsection{Tiempo de procesamiento de las salidas digitales}

El tiempo de procesamiento de las salidas digitales se evaluó mediante el contador de ciclos DWT del núcleo Cortex-M. La medición se realizó directamente sobre la llamada al controlador encargado de actualizar el VNI8200XP-32, excluyendo el tiempo de espera en la cola de mensajes y la latencia asociada a la planificación de tareas.

Para el ensayo se generaron 1000 solicitudes consecutivas de actualización desde la tarea de aplicación, alternando los patrones \texttt{0x00} y \texttt{0xFF}. La frecuencia del núcleo durante la prueba fue de 50 MHz.

De las 1000 operaciones procesadas, 999 finalizaron correctamente y una devolvió un estado de error. Dado que el objetivo del ensayo fue caracterizar el tiempo de ejecución de las operaciones válidas y que esta condición no afectó la continuidad de la prueba, los resultados temporales se calcularon sobre las 999 operaciones satisfactorias.

Se obtuvo un tiempo mínimo de 68,84~$\mu$s, un tiempo medio de aproximadamente 82,2~$\mu$s y un máximo observado de 326,36~$\mu$s. La repetición del ensayo presentó valores medios prácticamente equivalentes, lo que indica un comportamiento temporal estable para la operación evaluada. La diferencia entre el tiempo medio y el máximo observado puede atribuirse a la ejecución concurrente del sistema bajo FreeRTOS, dado que la medición incluye las posibles interrupciones o preempciones ocurridas durante la operación.

%----------------------------------------------------------------------------------------
\subsubsection{Tiempo de adquisición de las entradas digitales}

El tiempo de adquisición de las entradas digitales se evaluó mediante el contador de ciclos DWT del núcleo Cortex-M. La medición se realizó directamente sobre la llamada al controlador encargado de efectuar la lectura del SCLT3-8BT8, excluyendo la actualización posterior de la imagen de entradas, el acceso al mutex y el período de espera de la tarea.

Se registraron 1000 adquisiciones consecutivas con una frecuencia de núcleo de 50 MHz. Todas las operaciones finalizaron correctamente, sin registrarse errores durante el ensayo.

El tiempo mínimo observado fue de 59,78~$\mu$s, el tiempo medio de 60,22~$\mu$s y el máximo de 69,38~$\mu$s. La reducida diferencia entre los valores mínimo, medio y máximo evidencia un comportamiento temporal estable durante la adquisición de las entradas digitales.

%----------------------------------------------------------------------------------------
\subsubsection{Latencia de la comunicación inalámbrica}

La latencia de la comunicación inalámbrica entre una estación remota y la estación central se evaluó mediante un osciloscopio digital. Para ello, se instrumentó el firmware de ambos dispositivos utilizando una salida GPIO como referencia temporal. En la estación remota, la salida conmuta inmediatamente antes de iniciar la transmisión mediante el MRF24J40, mientras que en la estación central lo hace después de recibir y validar correctamente la trama.

El ensayo se realizó mediante transmisiones periódicas de tramas IEEE 802.15.4. La figura \ref{fig:latencia_radio} muestra las señales registradas, donde el canal 2 (celeste) corresponde a la estación remota transmisora y el canal 1 (amarillo) a la estación central receptora.

Se observaron tiempos de aproximadamente 4~ms entre los flancos correspondientes. Este intervalo comprende las operaciones de acceso al transceptor, la transmisión inalámbrica y el procesamiento de recepción hasta la validación de la trama. El resultado permite caracterizar la latencia extremo a extremo del enlace en las condiciones del ensayo.

\begin{figure}[H]
	\centering
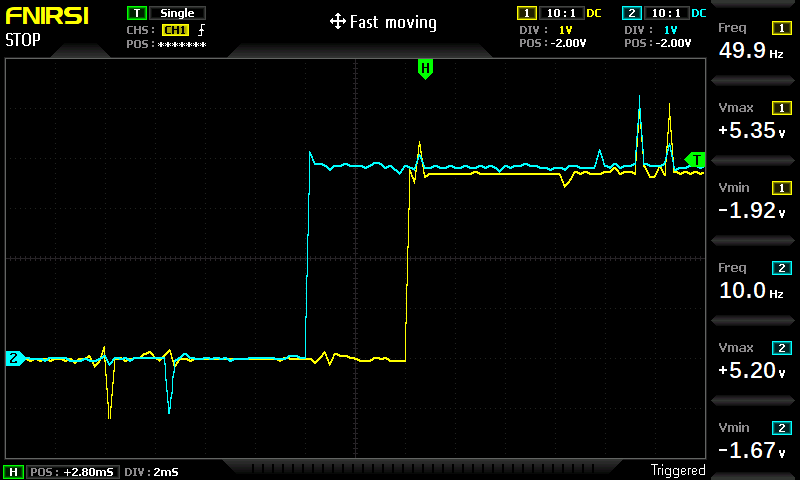
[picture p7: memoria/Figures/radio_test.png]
	
	\caption{Medición de la latencia de comunicación inalámbrica entre la estación remota y la estación central mediante osciloscopio.}
	\label{fig:latencia_radio}
\end{figure}

%----------------------------------------------------------------------------------------
\section{Ensayos de integración}

% PENDIENTE:
% Incorporar las pruebas funcionales realizadas sobre el sistema integrado.
% Documentar las condiciones de ensayo, los resultados esperados y obtenidos,
% y las evidencias correspondientes.

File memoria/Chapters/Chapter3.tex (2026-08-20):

\chapter{Diseño e implementación}
\label{Chapter3}

En el presente capítulo se describe el diseño e implementación del sistema desarrollado. Se presentan la arquitectura general de hardware y software, los criterios utilizados para la selección de componentes y las principales decisiones de diseño adoptadas durante el desarrollo. Asimismo, se detallan la estructura del firmware, las comunicaciones implementadas y la integración entre los distintos módulos del sistema.

%----------------------------------------------------------------------------------------
\section{Arquitectura del sistema}
La figura \ref{fig:arquitectura_general} presenta la arquitectura general del sistema desarrollado. La solución se compone de una estación central conectada mediante Ethernet TCP/IP a la interfaz de usuario y múltiples estaciones remotas enlazadas de forma inalámbrica mediante IEEE 802.15.4. Cada estación remota interactúa con variables de proceso asociadas a sensores, actuadores e interfaces industriales.

\begin{figure}[ht]
	\centering
	
	\caption{Arquitectura general del sistema implementado.}
	\label{fig:arquitectura_general}
\end{figure}

\subsection{Diagrama de bloques del hardware}

La figura \ref{fig:arquitectura_hardware} presenta el diagrama de bloques del hardware desarrollado. La arquitectura se basa en un microcontrolador encargado de gestionar las interfaces de comunicación, las entradas y salidas industriales y los módulos auxiliares del sistema. Asimismo, se distinguen los bloques comunes a las estaciones centrales y remotas y aquellos específicos de cada tipo de nodo.

Con el objetivo de uniformar el desarrollo y reducir costos durante una etapa inicial del trabajo, se implementó un único diseño de placa de circuito impreso PCB (\textit{Printed Circuit Board}, placa de circuito impreso) tanto para las estaciones centrales como para las estaciones remotas. Esta estrategia permitió reutilizar el mismo diseño base de hardware y poblar únicamente los componentes requeridos según las funcionalidades de cada estación. Además de simplificar el proceso de desarrollo, esta decisión redujo los costos de fabricación y facilitó las tareas de validación y mantenimiento del sistema.

La estación central incorpora un transceptor Ethernet para la comunicación con una interfaz de usuario ubicada en un nivel jerárquico superior. Asimismo, dispone de un reloj de tiempo real RTC (\textit{Real-Time Clock}, reloj de tiempo real), utilizado para el registro y mantenimiento de fecha y hora ante interrupciones en la alimentación principal.

Por otro lado, las estaciones remotas incorporan una interfaz RS485 para la comunicación con instrumentos industriales y módulos de entradas y salidas digitales destinados a la adquisición y accionamiento de variables de proceso.

Tanto las estaciones centrales como las remotas comparten los módulos de alimentación y regulación de tensión, el microcontrolador principal y el transceptor inalámbrico IEEE 802.15.4 utilizado para la comunicación entre nodos.

\begin{figure}[ht]
	\centering
	
	\caption{Diagrama de bloques general del hardware.}
	\label{fig:arquitectura_hardware}
\end{figure}

\subsection{Diagrama de bloques del firmware}

La figura \ref{fig:arquitectura_firmware} presenta la arquitectura general del firmware desarrollado para el sistema. Este fue organizado en capas con el objetivo de desacoplar la lógica de aplicación de las dependencias específicas del hardware, favorecer la modularidad del software y facilitar la reutilización de código entre estaciones centrales y remotas.

La capa superior implementa la lógica de control y supervisión del sistema. Por debajo se ubica una API (\textit{Application Programming Interface}, interfaz de programación de aplicaciones) encargada de abstraer el acceso a sensores, actuadores e interfaces de comunicación mediante una interfaz uniforme e independiente del hardware subyacente. Esta capa proporciona los servicios necesarios para que la aplicación de usuario pueda implementarse y adaptarse a distintos procesos productivos sin requerir modificaciones en las capas inferiores del firmware.

Las capas intermedias agrupan los servicios de \textit{middleware}, entre los que se encuentran la pila de protocolos lwIP y el sistema operativo en tiempo real FreeRTOS. La interacción entre la aplicación y el sistema operativo se realiza mediante la capa de abstracción CMSIS-RTOS2, que proporciona una interfaz estandarizada e independiente de la implementación particular del RTOS. De esta manera, la aplicación puede desarrollarse sin depender directamente de FreeRTOS, lo que facilita la portabilidad del software hacia otros sistemas operativos compatibles con CMSIS-RTOS2.

Finalmente, las capas inferiores comprenden los controladores de periféricos y comunicaciones, responsables del acceso a las interfaces de hardware, la capa HAL provista por STM32 y, en el nivel más bajo, los módulos físicos que conforman la plataforma, tales como el microcontrolador, el reloj de tiempo real y las interfaces industriales.

\begin{figure}[ht]
	\centering
	
	\caption{Diagrama de bloques general del firmware.}
	\label{fig:arquitectura_firmware}
\end{figure}

%----------------------------------------------------------------------------------------
\section{Diseño del hardware}

El diseño del hardware tuvo como objetivo materializar la arquitectura presentada en la sección anterior mediante una plataforma electrónica robusta, modular y adecuada para aplicaciones industriales. Para ello se seleccionaron componentes con características orientadas al entorno industrial y se adoptaron criterios de diseño que priorizaron la confiabilidad, la inmunidad frente a perturbaciones eléctricas, la facilidad de fabricación y la escalabilidad del sistema.

En las siguientes subsecciones se describen los principales bloques funcionales del hardware desarrollado, abordando las decisiones de diseño adoptadas, la selección de los componentes más relevantes y los criterios empleados para el diseño de la placa de circuito impreso.

\subsection{Plataforma de procesamiento}

El núcleo de procesamiento de la plataforma se implementó mediante el microcontrolador STM32H563ZI de STMicroelectronics, perteneciente a la familia STM32H5. La selección de este dispositivo respondió a la necesidad de disponer de una plataforma con suficiente capacidad de procesamiento para ejecutar simultáneamente tareas de adquisición de datos, control industrial y comunicaciones, permitiendo además incorporar futuras funcionalidades sin requerir modificaciones en la plataforma de procesamiento. La utilización de un mismo microcontrolador tanto en la estación central como en las estaciones remotas permitió unificar la arquitectura de hardware, simplificando el desarrollo del firmware y favoreciendo la reutilización de controladores, configuraciones de periféricos y capas de abstracción entre ambos tipos de nodos.

La disponibilidad de múltiples interfaces de comunicación independientes constituyó uno de los principales criterios para la selección del STM32H563ZI. Esta característica permitió asignar un periférico específico a cada uno de los módulos de la plataforma, evitando compartir recursos críticos y simplificando tanto el diseño del hardware como la implementación del firmware. La figura \ref{fig:main_schematic} resume esta distribución de periféricos y su interconexión con los principales módulos funcionales del sistema.

\begin{figure}[ht]
	\centering
	
	\caption{Asignación de interfaces del microcontrolador a los distintos módulos funcionales.}
	\label{fig:main_schematic}
\end{figure}

Se seleccionó la variante STM32H563ZI en encapsulado LQFP64, cuya disponibilidad de periféricos y líneas de entrada y salida resultó suficiente para implementar todas las funcionalidades previstas en la plataforma. Asimismo, al pertenecer a la misma familia de microcontroladores empleada en la placa de evaluación NUCLEO-H563ZI, fue posible desarrollar y validar las primeras versiones del firmware sobre dicha plataforma y, posteriormente, migrarlas al hardware desarrollado con modificaciones mínimas. Esta estrategia permitió reducir los tiempos de desarrollo, aprovechar los ejemplos y bibliotecas proporcionados por STMicroelectronics y disminuir los riesgos asociados a la puesta en marcha del prototipo.

Todas estas características permitieron disponer de una plataforma de procesamiento capaz de satisfacer los requerimientos funcionales del sistema, manteniendo un elevado grado de reutilización del hardware y del firmware entre las distintas variantes de la plataforma.

\subsection{Sistema de alimentación}

Esta etapa fue diseñada para proporcionar un dominio de alimentación aislado de 5 V a partir de una alimentación industrial nominal de 24 V, garantizando además un elevado nivel de robustez frente a las condiciones eléctricas habituales presentes en entornos industriales. La tensión de entrada de 24 V se distribuye directamente hacia las etapas de entradas y salidas industriales, mientras que la electrónica de procesamiento dispone de una alimentación aislada de 5 V, a partir de donde se obtiene posteriormente la tensión de 3,3 V utilizada por el microcontrolador y los circuitos digitales. Esta arquitectura permite desacoplar eléctricamente la lógica de control del dominio de potencia industrial, mejorando la inmunidad frente a perturbaciones y diferencias de potencial. El esquema eléctrico de esta etapa se presenta en la figura \ref{fig:pwr_schematic}.

La conversión de energía se realiza mediante el módulo convertidor CC-CC aislado 1769405341 de Würth Elektronik, que admite una tensión de entrada nominal de 24 V y entrega una salida regulada de 5 V con una capacidad de corriente de hasta 400 mA. El convertidor incorpora aislamiento galvánico entre la entrada y la salida, proporcionando una tensión de aislamiento de 1 kV, lo que permite desacoplar eléctricamente la electrónica de control respecto del dominio de alimentación industrial y reducir la propagación de perturbaciones y diferencias de potencial provenientes del entorno industrial.

Con el objetivo de aumentar la inmunidad frente a perturbaciones electromagnéticas, tanto la entrada como la salida del convertidor incorporan capacitores de desacople ubicados próximos al módulo. Estos elementos reducen el ruido conducido y estabilizan la tensión de alimentación, lo que contribuye al correcto funcionamiento de la electrónica digital.

\newpage

\begin{figure}[ht]
	\centering
	
	\caption{Esquema eléctrico de la etapa de alimentación.}
	\label{fig:pwr_schematic}
\end{figure}

La protección de la entrada contempla múltiples mecanismos destinados a incrementar la confiabilidad del sistema. Un fusible de 10 A constituye la primera barrera frente a condiciones de sobrecorriente o cortocircuito, limitando la energía disponible durante una falla. A continuación, un diodo TVS de 26 V protege al convertidor frente a sobretensiones transitorias generadas sobre la línea de alimentación, mientras que un diodo \textit{Schottky} conectado en serie impide la circulación de corriente en sentido inverso, proporcionando protección frente a inversiones accidentales de polaridad y evitando daños sobre los circuitos posteriores.

A partir de la tensión aislada de 5 V se obtiene la alimentación de 3,3 V utilizada por el microcontrolador y los circuitos lógicos mediante un regulador lineal LD1117DT33CTR de STMicroelectronics. Dado que la demanda de corriente sobre la línea de 3,3 V resulta relativamente reducida, el empleo de un regulador lineal constituye una solución simple, de bajo costo y con un bajo nivel de ruido, lo que hace innecesario incorporar una segunda etapa de conversión conmutada.

\subsection{Entradas digitales}

Las estaciones remotas fueron concebidas para interactuar directamente con sensores industriales mediante entradas digitales compatibles con señales de 24 V, permitiendo la adquisición confiable de estados discretos provenientes de sensores, interruptores y dispositivos de campo.

Para implementar las entradas digitales se seleccionó el circuito integrado SCLT3-8BT8 de STMicroelectronics, un receptor de ocho canales específicamente desarrollado para aplicaciones de automatización industrial y compatible con los requisitos de la norma IEC 61131-2 \cite{iec61131_2} para entradas digitales de PLC.

El dispositivo incorpora el acondicionamiento necesario para la conexión directa de señales industriales de 24 V, integrando protección frente a sobretensiones, filtrado de ruido, detección del estado lógico y comunicación con el microcontrolador mediante una interfaz SPI. Esta solución reduce significativamente la cantidad de componentes discretos necesarios respecto de una implementación convencional basada en optoacopladores, comparadores y circuitos de protección individuales.

\subsection{Salidas digitales}

Las estaciones remotas incorporan salidas digitales destinadas al accionamiento de cargas industriales alimentadas a 24 V, tales como relés, electroválvulas, contactores y otros actuadores utilizados habitualmente en sistemas de automatización.

Las salidas digitales se implementaron mediante el circuito integrado VNI8200XP-32 de STMicroelectronics, un controlador inteligente de ocho salidas \textit{high-side} diseñado para aplicaciones industriales. Cada canal puede operar con tensiones comprendidas entre 10,5 V y 36 V, suministrando hasta 1 A de corriente continua.

El dispositivo integra protección individual frente a sobrecorriente, cortocircuito y sobretemperatura, además de diagnóstico del estado de alimentación y detección de fallas mediante interfaz SPI. Estas características incrementan la confiabilidad del sistema y permiten detectar condiciones anómalas sin necesidad de circuitería adicional.

Debido a que las cargas industriales se alimentan desde una fuente de 24 V independiente de la electrónica de control y la comunicación con el microcontrolador se realiza mediante una interfaz digital SPI aislada del dominio de potencia, la arquitectura implementada preserva el aislamiento galvánico requerido entre la lógica de control y las salidas industriales.

\subsection{Interfaz RS485}

Con el objetivo de permitir la integración de las estaciones remotas con equipos industriales externos, el sistema incorpora una interfaz de comunicación diferencial basada en el estándar RS485.

La comunicación cableada con equipos industriales se implementó mediante un transceptor diferencial SN65HVD82 de Texas Instruments, compatible con el estándar TIA/EIA-485-A \cite{tia_eia485a}. El dispositivo opera sobre buses multipunto de dos hilos y soporta velocidades de transmisión de hasta 200 kb/s en enlaces de aproximadamente 1200 m.

El transceptor se conecta al microcontrolador mediante una interfaz UART y una señal adicional de control de dirección, lo que permite la implementación de enlaces semidúplex compatibles con la mayoría de los instrumentos industriales y dispositivos de automatización disponibles comercialmente.

\subsection{Interfaz inalámbrica}

La comunicación entre la estación central y las estaciones remotas se implementó mediante el módulo de radiofrecuencia MRF24J40MA de Microchip Technology, un transceptor compatible con el estándar IEEE 802.15.4 \cite{ieee_standard} que opera en la banda ISM de 2,4 GHz. El módulo integra el transceptor de radio, el cristal de referencia, la red de adaptación de impedancias, el regulador interno y una antena impresa sobre la propia placa, lo que reduce la complejidad del diseño de RF y simplifica su integración en el sistema.

El MRF24J40MA se comunica con el microcontrolador mediante una interfaz SPI de cuatro hilos, complementada con señales dedicadas de interrupción, reinicio y activación, permitiendo una integración sencilla con la arquitectura de firmware desarrollada para el proyecto. Asimismo, el módulo soporta una velocidad física de transmisión de 250 kb/s y un alcance de hasta aproximadamente 120 m en condiciones de línea de vista, superando ampliamente el requerimiento de al menos 20 m de cobertura en ambientes interiores establecido para el sistema.

Desde el punto de vista del protocolo de comunicación, la implementación se basa en las capacidades proporcionadas por la capa MAC del estándar IEEE 802.15.4, que incorpora de forma nativa mecanismos de acuse automático de recibo y retransmisión automática de tramas no confirmadas, lo que satisface el requerimiento de confiabilidad definido para el enlace inalámbrico. Adicionalmente, el hardware implementa mecanismos de acceso al medio mediante CSMA/CA, verificación automática de la integridad de las tramas y medición de la calidad del enlace, lo que ayuda a mejorar la robustez de la comunicación en entornos industriales.

\subsection{Interfaz Ethernet}

La estación central incorpora una interfaz Ethernet. Para ello se seleccionó el circuito integrado LAN8742A de Microchip Technology, un transceptor Ethernet (\textit{PHY}) compatible con el estándar IEEE 802.3 \cite{ieee8023} para redes 10BASE-T y 100BASE-TX.

El LAN8742A se conecta al microcontrolador mediante la interfaz RMII (\textit{Reduced Media Independent Interface}), mientras que la pila de protocolos TCP/IP es ejecutada por el propio STM32H563 mediante el middleware lwIP. Esta arquitectura permite desacoplar las funciones correspondientes a la capa física de las implementadas por el microcontrolador, proporcionando una solución ampliamente utilizada en sistemas embebidos con conectividad Ethernet.

La interfaz implementada admite velocidades de operación de 10 y 100 Mb/s con negociación automática, cumpliendo el requerimiento de disponer de conectividad Ethernet 10/100 para la integración con sistemas SCADA y otras aplicaciones de supervisión industrial. Asimismo, la utilización de una interfaz cableada dedicada en la estación central permite separar el enlace inalámbrico utilizado para la comunicación con las estaciones remotas de la red de supervisión, lo que simplifica la integración del sistema dentro de infraestructuras industriales existentes.

\subsection{Diseño del PCB}

El diseño del PCB se realizó considerando los requerimientos funcionales del sistema y la necesidad de obtener una solución de bajo costo de fabricación. Para ello, se optó por una placa de dos capas, cuya densidad de interconexión resultó suficiente para integrar todos los módulos de la plataforma sin recurrir a una estructura multicapa.

Durante el diseño se siguieron las recomendaciones establecidas por los estándares IPC-2221A \cite{ipc2221a} e IPC-2222 \cite{ipc2222} para el desarrollo de circuitos impresos, contemplando criterios relacionados con el dimensionamiento de pistas, separación entre conductores, distribución de planos de masa y compatibilidad electromagnética. Asimismo, los \textit{footprints} de los componentes fueron desarrollados conforme a la norma IPC-7351 \cite{ipc7351}, mientras que la elaboración de los esquemáticos adoptó la simbología definida por el estándar IEEE Std 315-1975 \cite{ieee315}, garantizando uniformidad y compatibilidad con las prácticas habituales de diseño electrónico.

Como resultado de este proceso se obtuvo el diseño de la placa mostrado en la figura \ref{fig:pcb_3d_top}, en el cual se integran los distintos bloques funcionales descritos previamente. La distribución de los componentes se realizó procurando mantener una organización física acorde con las funciones de cada subsistema y facilitar el acceso a los conectores e interfaces externas de la plataforma.

\begin{figure}[ht]
	\centering
	
	\caption{Vista tridimensional del PCB desarrollado.}
	\label{fig:pcb_3d_top}
\end{figure}

%----------------------------------------------------------------------------------------
\section{Diseño del firmware}

El firmware desarrollado para el sistema fue diseñado con una arquitectura modular orientada a facilitar su mantenimiento, escalabilidad y reutilización entre las distintas variantes de la plataforma. Para ello, se adoptó un sistema operativo de tiempo real que permite organizar la ejecución del software en múltiples tareas concurrentes, coordinadas mediante mecanismos de sincronización y comunicación entre procesos.

En esta sección se describe la organización general del firmware, el proceso de inicialización del sistema, la distribución de responsabilidades entre las distintas tareas, el manejo de interrupciones, la estructura de los drivers y la lógica de control implementada.

\subsection{Organización general del firmware}

El firmware fue concebido como un conjunto de módulos independientes que ejecutan funciones específicas de manera concurrente sobre FreeRTOS. Esta organización permite distribuir las distintas responsabilidades del sistema entre tareas dedicadas, lo que favorece a una arquitectura modular, escalable y fácilmente mantenible. La interacción entre tareas se realiza exclusivamente mediante interfaces de aplicación bien definidas, evitando el acceso directo a los recursos administrados por otros módulos y promoviendo un bajo acoplamiento entre las distintas funcionalidades del sistema.

Dado que la estación central y las estaciones remotas poseen responsabilidades diferentes, el firmware adopta una organización particular para cada una de ellas. No obstante, ambas implementaciones comparten la misma filosofía de diseño, donde la tarea \texttt{userTask} concentra la lógica de aplicación, mientras que el acceso a cada periférico o servicio del sistema se realiza mediante tareas específicas.

La figura \ref{fig:firmware_master} presenta la organización general del firmware implementado en la estación central. En esta arquitectura, la tarea \texttt{userTask} interactúa con la comunicación inalámbrica mediante las funciones \texttt{app\_rf\_send()} y \texttt{app\_rf\_\-receive()}, delegando su ejecución a la tarea \texttt{rfTask}. De forma análoga, las operaciones relacionadas con el reloj en tiempo real se realizan mediante las funciones \texttt{app\_rtc\_set()} y \texttt{app\_rtc\_get()}, administradas por la tarea \texttt{rtc\-Task}. Adicionalmente, la tarea \texttt{diagnosticsTask} centraliza el tratamiento de las condiciones de falla notificadas por los distintos módulos mediante los eventos \texttt{ra\-dioFaultHandle}, \texttt{rtcFaultHandle} y \texttt{diagnosticsFaultHandle}, lo que proporciona un mecanismo unificado para la supervisión del sistema.

\begin{figure}[ht]
	\centering
	
	\caption{Organización general del firmware de la estación central.}
	\label{fig:firmware_master}
\end{figure}

Por su parte, la figura \ref{fig:firmware_slave} muestra la organización correspondiente a las estaciones remotas. En este caso, además de la tarea \texttt{rfTask}, el firmware incorpora las tareas \texttt{dinTask}, \texttt{doutTask} y \texttt{rs485Task}, responsables de administrar las entradas digitales, las salidas digitales y la interfaz RS485, respectivamente. La tarea \texttt{userTask} accede a estos recursos mediante las funciones \texttt{app\_din\_read()}, \texttt{app\_dout\_set()}, \texttt{app\_rs485\_send()}, \texttt{app\_rs485\_receive()}, \texttt{app\_rf\_\-send()} y \texttt{app\_rf\_receive()}, lo que mantiene desacoplada la lógica de aplicación de la implementación específica de cada periférico. Al igual que en la estación central, las distintas tareas reportan las condiciones de error mediante los eventos \texttt{dinFaultHandle}, \texttt{doutFaultHandle}, \texttt{rs485FaultHandle}, \texttt{radio\-FaultHandle} y \texttt{diagnosticsFaultHandle}, que son procesadas por la tarea \texttt{diagnosticsTask}.

\begin{figure}[ht]
	\centering
	
	\caption{Organización general del firmware de las estaciones remotas.}
	\label{fig:firmware_slave}
\end{figure}

En ambas arquitecturas, esta división funcional permite encapsular la gestión de cada subsistema en tareas independientes, simplificando la incorporación de nuevas funcionalidades y facilitando el mantenimiento del firmware. Asimismo, el empleo de interfaces de aplicación estandarizadas reduce las dependencias entre módulos y proporciona una separación clara entre la lógica de control implementada por \texttt{userTask} y los mecanismos de acceso a los recursos físicos del sistema.

\subsection{Organización de las tareas}

Las tareas que conforman el firmware presentan distintos modos de ejecución y utilizan los mecanismos proporcionados por CMSIS-RTOS2 para su coordinación y acceso a recursos compartidos. A continuación, se describen las responsabilidades y los principales recursos asociados a cada una de ellas.

\subsubsection{Tarea de entradas digitales}

La tarea \texttt{dinTask} es responsable de mantener actualizado el estado de las entradas digitales de la estación remota. Para ello, realiza periódicamente la lectura del SCLT3-8BT8 y almacena la última imagen de entradas obtenida correctamente. La periodicidad de adquisición se establece mediante un retardo proporcionado por CMSIS-RTOS2, de manera que la tarea permanece bloqueada entre lecturas y libera tiempo de procesamiento para la ejecución del resto de las tareas del sistema.

El acceso a la última imagen válida se encuentra protegido mediante el mutex \texttt{dinDataMutex}, ya que esta información puede ser actualizada por \texttt{dinTask} y consultada simultáneamente desde otras tareas. La función \texttt{app\_din\_read()} proporciona la interfaz de acceso a estos datos y devuelve una copia de la última imagen disponible sin realizar una nueva adquisición del hardware. De esta manera, las demás tareas pueden consultar el estado de las entradas sin acceder directamente al SCLT3-8BT8 ni interferir con la ejecución periódica de \texttt{dinTask}.

Debido a que los circuitos de entradas y salidas digitales comparten el mismo periférico SPI, el acceso físico al bus se encuentra protegido mediante el mutex \texttt{ioPortSpiMutex} en la capa encargada de gestionar dicho recurso. Esto evita que las tareas asociadas a ambos subsistemas inicien transferencias simultáneas y garantiza el acceso exclusivo al periférico durante cada operación.

Cuando durante la adquisición se detecta una condición de falla, \texttt{dinTask} la informa mediante el grupo de banderas de eventos \texttt{dinFault}, lo que hace posible que su tratamiento sea realizado posteriormente por la tarea de diagnóstico. De esta forma, la adquisición de las entradas permanece separada tanto de la lógica de aplicación como del procesamiento de las condiciones de error.

\subsubsection{Tarea de salidas digitales}

La tarea \texttt{doutTask} es responsable de gestionar la actualización de las salidas digitales de la estación remota. A diferencia de la tarea de entradas digitales, su ejecución no es periódica, sino que permanece bloqueada hasta que se recibe una nueva solicitud de actualización. Las demás tareas pueden establecer el estado deseado de las salidas mediante la función \texttt{app\_dout\_set()}, que incorpora la nueva imagen de salidas en la cola de mensajes \texttt{outOutputQueue}.

Cuando existe una nueva imagen disponible, \texttt{doutTask} se desbloquea, extrae el dato de la cola y realiza la actualización del VNI8200XP-32. Este mecanismo desacopla la generación de una orden de salida de su ejecución sobre el hardware, evitando que la tarea solicitante deba acceder directamente al controlador o esperar a que finalice la transferencia correspondiente. Cuando no existen solicitudes pendientes, la tarea permanece bloqueada y no consume tiempo de procesamiento.

Al igual que en el módulo de entradas digitales, el acceso al periférico SPI compartido se encuentra protegido mediante el mutex \texttt{ioPortSpiMutex}. La adquisición y liberación de este recurso se realiza en la capa encargada de gestionar el acceso físico al bus, garantizando que las operaciones sobre el SCLT3-8BT8 y el VNI8200XP-32 se ejecuten de manera mutuamente excluyente. De esta forma, \texttt{dinTask} y \texttt{doutTask} pueden operar de manera concurrente sin producir transferencias simultáneas sobre el mismo periférico SPI.

Las condiciones de falla detectadas durante la actualización de las salidas, así como los errores asociados al funcionamiento de la cola, se notifican mediante el grupo de banderas de eventos \texttt{doutFault}. Esto permite delegar su tratamiento a la tarea de diagnóstico y mantener separadas las responsabilidades de accionamiento y supervisión del sistema.

\subsubsection{Tarea de comunicación RS485}

La tarea \texttt{rs485Task} administra la interfaz RS485 y centraliza el acceso al controlador de comunicación asociado. Su funcionamiento se basa en un esquema asíncrono: la tarea permanece normalmente bloqueada a la espera de eventos y se activa cuando se completa una recepción, existe una solicitud de transmisión, finaliza una transmisión o se detecta una condición de error. Para ello se utiliza el grupo de banderas de eventos \texttt{rs485EventHandle}, lo que evita el sondeo continuo del periférico.

El intercambio de datos con las demás tareas se realiza mediante dos colas de mensajes. La función \texttt{app\_rs485\_send()} incorpora los datos pendientes en \texttt{rs485OutputQueueHandle} y notifica a \texttt{rs485Task} mediante una bandera de evento. Los datos recibidos se almacenan en \texttt{rs485InputQueueHandle} y pueden recuperarse mediante la función no bloqueante \texttt{app\_rs485\_receive()}. Esta organización desacopla las tareas de aplicación de las operaciones físicas de transmisión y recepción y evita el acceso directo al driver RS485.

Debido al funcionamiento semidúplex de la interfaz, \texttt{rs485Task} también coordina la alternancia entre recepción y transmisión. En condiciones normales se mantiene activa una operación de recepción por interrupciones. Cuando existe información pendiente de transmisión, la recepción se suspende y se inicia el envío del siguiente dato disponible en la cola. Una vez finalizada la transmisión, la tarea procesa las solicitudes restantes o restablece la recepción si no existen nuevos datos pendientes. Las interrupciones asociadas a la UART notifican la finalización de las operaciones mediante las funciones de retorno \texttt{rs485\_rx\_complete\_\-callback()} y \texttt{rs485\_tx\_complete\_callback()}. La gestión de las colas y la secuenciación de las operaciones se realizan desde el contexto de \texttt{rs485Task}.

Las fallas detectadas durante la inicialización o las operaciones de comunicación, junto con los errores asociados a las colas y los servicios del sistema operativo, se informan mediante el grupo de banderas \texttt{rs485FaultHandle}. Su tratamiento puede delegarse a la tarea de diagnóstico, lo que mantiene separadas las responsabilidades de comunicación, lógica de aplicación y supervisión del sistema.

\subsubsection{Tarea de comunicación inalámbrica}

La tarea \texttt{radioTask} administra la interfaz de comunicación inalámbrica y centraliza el acceso al transceptor MRF24J40. Su funcionamiento se basa en un esquema orientado a eventos, por lo que permanece normalmente bloqueada hasta que se produce una interrupción del transceptor o existe información pendiente de transmisión. Para ello se utiliza el grupo de banderas de eventos \texttt{radioEvent\-Handle}, lo que evita el sondeo continuo del dispositivo y libera tiempo de procesamiento mientras no existen operaciones pendientes.

El intercambio de información con las demás tareas se realiza mediante dos colas de mensajes. La función \texttt{app\_radio\_send()} incorpora en \texttt{radioOutput\-QueueHandle} el dato que se desea transmitir junto con la dirección del nodo de destino y notifica a \texttt{radioTask} mediante una bandera de evento. Los datos recibidos correctamente se almacenan en \texttt{radioInputQueueHandle} junto con la dirección del nodo de origen y pueden recuperarse mediante la función no bloqueante \texttt{app\_radio\_receive()}. Esta organización permite intercambiar información a través del enlace inalámbrico sin acceder directamente al controlador MRF24J40.

La recepción de datos y la finalización de las transmisiones son notificadas por el transceptor mediante su línea de interrupción. La interrupción externa únicamente registra la condición pendiente y establece la bandera correspondiente en \texttt{radioEventHandle}; el procesamiento se realiza posteriormente desde el contexto de \texttt{radioTask}. La tarea determina entonces el origen de la interrupción y, según corresponda, procesa la información recibida o finaliza la transmisión en curso. Este mecanismo reduce el procesamiento realizado en contexto de interrupción y concentra las operaciones de acceso al transceptor en una única tarea.

Las solicitudes de transmisión se procesan secuencialmente y se mantiene una única operación activa sobre el transceptor. Una vez finalizada cada transmisión, \texttt{radioTask} puede iniciar el envío del siguiente elemento almacenado en \texttt{radioOutputQueueHandle}. La cola desacopla así la generación de solicitudes por parte de las tareas de aplicación de su ejecución sobre el hardware, mientras que \texttt{radioTask} mantiene el control exclusivo del MRF24J40.

Las fallas detectadas durante el acceso al transceptor, el procesamiento de los datos o la utilización de los recursos del sistema operativo se informan mediante el grupo de banderas \texttt{radioFaultHandle}. Este recurso también permite registrar condiciones asociadas al resultado de las transmisiones. Su tratamiento puede delegarse a la tarea de diagnóstico, lo que mantiene separadas las responsabilidades de comunicación inalámbrica, lógica de aplicación y supervisión del sistema.

\subsubsection{Tarea de reloj de tiempo real}

La tarea \texttt{rtcTask} mantiene actualizada la información de fecha y hora utilizada por la estación central. Para ello emplea el periférico RTC integrado en el microcontrolador, cuya base de tiempo se obtiene mediante un cristal externo de 32,768 kHz. El dominio correspondiente dispone de alimentación de respaldo por batería, lo que permite conservar la referencia temporal ante la interrupción de la alimentación principal del sistema.

La tarea realiza periódicamente la lectura del RTC y mantiene una copia actualizada de la información temporal para el resto del firmware. Las demás tareas pueden consultarla mediante la función \texttt{app\_rtc\_get()}, sin acceder directamente al periférico. A su vez, la función \texttt{app\_rtc\_set()} permite establecer una nueva fecha y hora cuando sea necesario. De esta manera, las operaciones relacionadas con la referencia temporal quedan centralizadas en este módulo.

El acceso a la información temporal se gestiona para evitar inconsistencias entre su actualización por \texttt{rtcTask} y su consulta desde otras tareas. Así, el resto del firmware dispone de una interfaz común para obtener o modificar la fecha y hora, mientras que los detalles del manejo del RTC permanecen encapsulados en el módulo correspondiente.

Las fallas detectadas durante la configuración o el acceso al RTC se informan mediante el grupo de banderas \texttt{rtcFaultHandle}. Su tratamiento puede delegarse a la tarea de diagnóstico, lo que mantiene separadas las responsabilidades asociadas a la referencia temporal y a la supervisión general del sistema.

\subsubsection{Tarea de usuario}

La tarea \texttt{userTask} ejecuta la lógica de aplicación específica del proceso productivo en el que se utiliza el sistema. A diferencia de las tareas anteriores, no se encuentra asociada directamente a un periférico o subsistema particular, sino que utiliza las interfaces proporcionadas por los distintos módulos del firmware para implementar las funciones de adquisición, control y comunicación requeridas por cada aplicación.

El acceso a los recursos del sistema se realiza exclusivamente mediante las interfaces de aplicación correspondientes. \texttt{userTask} puede consultar el estado de las entradas digitales mediante \texttt{app\_din\_read()}, establecer las salidas mediante \texttt{app\_dout\_set()}, intercambiar información mediante \texttt{app\_radio\_send()}, \texttt{app\_radio\_receive()}, \texttt{app\_rs485\_send()} y \texttt{app\_rs485\_receive()}, y acceder a la referencia temporal mediante \texttt{app\_rtc\_get()} y \texttt{app\_rtc\_set()}. De esta forma, la lógica de usuario permanece desacoplada del acceso directo a los periféricos y de los detalles internos de cada controlador.

La estructura de \texttt{userTask} contempla una etapa de inicialización seguida de un ciclo de ejecución periódico, en el que pueden incorporarse las funciones requeridas por el proceso. El retardo entre ejecuciones se implementa mediante los servicios proporcionados por CMSIS-RTOS2, lo que permite definir una periodicidad acorde con las necesidades de la aplicación y evita la ocupación continua del procesador.

Esta organización permite adaptar el firmware a diferentes procesos productivos mediante la modificación principal del comportamiento de \texttt{userTask}, mientras que las tareas encargadas de administrar los recursos de hardware pueden mantenerse sin cambios. La tarea de usuario constituye así el nivel de integración entre los servicios proporcionados por la plataforma y la lógica de control específica de cada aplicación.

\subsubsection{Tarea de diagnóstico}

La tarea \texttt{diagnosticsTask} centraliza la supervisión de las condiciones de falla detectadas por los distintos módulos del firmware. Para ello consulta los grupos de banderas asociados a las entradas digitales, las salidas digitales, la comunicación inalámbrica, la interfaz RS485 y el reloj de tiempo real mediante los objetos \texttt{dinFaultHandle}, \texttt{doutFaultHandle}, \texttt{radioFaultHandle}, \texttt{rs485Fault\-Handle} y \texttt{rtcFaultHandle}, respectivamente.

En la implementación actual, \texttt{diagnosticsTask} captura las banderas de error pendientes y las reporta mediante la interfaz de depuración SWO. Este mecanismo resulta útil durante las etapas de desarrollo y validación, ya que permite identificar el origen y el tipo de falla sin incorporar procesamiento adicional en las tareas que administran cada subsistema.

Como evolución de esta implementación, se prevé incorporar una estrategia de gestión de fallas que permita clasificarlas según su severidad, registrar su estado y notificar las condiciones relevantes a \texttt{userTask}. De esta forma, la lógica de aplicación podrá adoptar las acciones correspondientes ante situaciones anómalas, mientras que la detección y consolidación de los errores permanecerán centralizadas en una única tarea.

\section{Comunicaciones e interfaces}

La comunicación entre los distintos elementos del sistema se implementó mediante dos interfaces con objetivos diferentes. El enlace inalámbrico entre la estación central y las estaciones remotas utiliza una implementación basada en IEEE 802.15.4 sobre el transceptor MRF24J40, con direccionamiento de nodos y mecanismos de confirmación de las transmisiones. Por su parte, las estaciones remotas disponen de una interfaz RS485 destinada a la comunicación cableada con dispositivos externos, sobre la cual se implementó inicialmente un mecanismo propietario básico de intercambio de datos.

En ambos casos, las capas de comunicación se diseñaron para desacoplar la lógica de aplicación de los detalles asociados al acceso físico a los periféricos. Las operaciones de transmisión y recepción se gestionan de forma asíncrona y los errores detectados se propagan hacia los mecanismos de diagnóstico descritos previamente.

\subsection{Comunicación inalámbrica}

La comunicación inalámbrica se implementó mediante una red con topología en estrella, compuesta por una estación central configurada como coordinador PAN y hasta dieciséis estaciones remotas. Todos los nodos pertenecen a una misma PAN, identificada mediante un valor fijo, y utilizan direccionamiento corto de 16 bits. La estación central utiliza la dirección \texttt{0x0000}, mientras que las estaciones remotas emplean direcciones comprendidas entre \texttt{0x0001} y \texttt{0x0010}. El rol y la dirección local de cada nodo se establecen durante la compilación del firmware.

La red opera en modo \textit{nonbeacon}, sin mecanismos de asociación, descubrimiento ni asignación dinámica de direcciones. En consecuencia, la estación central conoce previamente las direcciones de los nodos de la red y cada estación remota se comunica exclusivamente con el coordinador. Este esquema simplifica la implementación y resulta suficiente para la topología fija definida para el sistema.

Sobre la capa MAC de IEEE 802.15.4 se implementó una trama de aplicación mínima destinada al intercambio de un byte de información. Su estructura se presenta en la tabla \ref{tab:radio_frame}. La cabecera MAC ocupa nueve bytes e incorpora el campo de control de trama, el número de secuencia, el identificador de la PAN y las direcciones cortas de destino y origen. A continuación, se incorpora un byte correspondiente a la información de aplicación. El campo FCS (\textit{Frame Check Sequence}, secuencia de verificación de trama) no es incorporado por el firmware, ya que el MRF24J40 lo genera y verifica automáticamente.

\begin{table}[h]
	\centering
	\caption[Formato de la trama inalámbrica]{Formato de la trama utilizada para la comunicación inalámbrica.}
	\begin{tabular}{l c l}
		\toprule
		\textbf{Campo}      & \textbf{Tamaño} & \textbf{Descripción} \\
		\midrule
		Frame Control       & 2 bytes         & Configuración de la trama IEEE 802.15.4 \\
		Sequence Number     & 1 byte          & Número de secuencia \\
		Destination PAN ID  & 2 bytes         & Identificador de la red \\
		Destination Address & 2 bytes         & Dirección corta del nodo de destino \\
		Source Address      & 2 bytes         & Dirección corta del nodo de origen \\
		Payload             & 1 byte          & Dato de aplicación \\
		\bottomrule
	\end{tabular}
	\label{tab:radio_frame}
\end{table}

La transmisión se inicia mediante \texttt{app\_radio\_send()}, que recibe la dirección de destino y el byte que se desea enviar. La información se almacena en una cola hasta que \texttt{radioTask} puede procesarla. La tarea construye la trama correspondiente y la carga en la FIFO de transmisión del MRF24J40. Durante la recepción, el transceptor genera una interrupción cuando existe una nueva trama disponible. Posteriormente, \texttt{radioTask} recupera la información, verifica que la trama corresponda al formato esperado y extrae la dirección de origen y el dato recibido. Esta información queda disponible para la aplicación mediante \texttt{app\_radio\_receive()}.

Todas las tramas de datos se transmiten con solicitud de acuse de recibo. La generación y detección del ACK, así como las retransmisiones ante la ausencia de confirmación, son realizadas automáticamente por el MRF24J40. Una vez finalizado este procedimiento, el firmware consulta el resultado y distingue entre una transmisión exitosa, una falla por ausencia de ACK luego de agotar las retransmisiones y una falla de acceso al medio asociada al mecanismo CSMA/CA. Estas condiciones, junto con los errores de acceso al hardware, las tramas inválidas y los desbordamientos de las colas, se informan mediante \texttt{radioFaultHandle} para su posterior tratamiento por el sistema de diagnóstico.

\subsection{Comunicación mediante RS485}

La interfaz RS485 se implementó inicialmente mediante un mecanismo propietario básico orientado al intercambio asíncrono de datos entre la estación remota y dispositivos externos. En su estado actual, cada operación de transmisión o recepción procesa un único byte, por lo que todavía no se incorporaron campos adicionales de direccionamiento, delimitación de trama, comandos ni mecanismos de verificación mediante suma de comprobación o CRC. Esta solución constituye una interfaz mínima sobre la que pueden incorporarse posteriormente protocolos de mayor complejidad sin modificar las capas encargadas del acceso al hardware.

La transmisión y la recepción utilizan la UART del microcontrolador mediante interrupciones. La capa de bajo nivel controla además las señales DE y /RE del transceptor RS485 para alternar entre los modos de transmisión y recepción. Debido al funcionamiento semidúplex de la interfaz, solo puede existir una operación activa en cada instante. El estado de reposo corresponde al modo de recepción, con el transmisor deshabilitado y el receptor habilitado.

El formato utilizado actualmente se limita al byte de aplicación indicado en la tabla \ref{tab:rs485_frame}. Su interpretación depende de la lógica implementada en las capas superiores y no forma parte del driver RS485.

\begin{table}[h]
	\centering
	\caption[Unidad de datos RS485]{Unidad de datos utilizada por la interfaz RS485.}
	\begin{tabular}{l c l}
		\toprule
		\textbf{Campo} & \textbf{Tamaño} & \textbf{Descripción} \\
		\midrule
		Payload        & 1 byte          & Dato intercambiado con el dispositivo externo \\
		\bottomrule
	\end{tabular}
	\label{tab:rs485_frame}
\end{table}

La función \texttt{app\_rs485\_send()} incorpora el dato en la cola de transmisión y retorna inmediatamente, sin esperar a que finalice la transferencia física. Cuando \texttt{rs485Task} procesa la solicitud, suspende una eventual recepción activa, configura el transceptor en modo de transmisión e inicia el envío mediante interrupciones. Una vez transmitido el byte, el controlador retorna al modo de recepción y notifica a la tarea para que procese el siguiente dato pendiente o restablezca la espera de una nueva recepción.

La recepción permanece normalmente activa mientras no existan transmisiones pendientes. Cuando la UART recibe un byte, genera una interrupción y la información se procesa posteriormente desde el contexto de \texttt{rs485Task}. El dato se almacena en la cola de recepción y queda disponible para las demás tareas mediante \texttt{app\_rs485\_receive()}.

El manejo de errores contempla condiciones asociadas a la inicialización, estados inválidos del controlador, tiempos de espera, fallas de hardware y errores informados por la UART. Ante una condición anómala, la operación activa se considera finalizada, el transceptor retorna al modo de recepción y la condición correspondiente se informa mediante \texttt{rs485FaultHandle}. También se supervisan los posibles desbordamientos de las colas de transmisión y recepción y los errores asociados a los servicios del sistema operativo.

%----------------------------------------------------------------------------------------
\section{Integración hardware-software}

La integración entre los módulos de hardware y software se realizó de acuerdo con la arquitectura en capas presentada en las secciones anteriores. Los periféricos físicos son gestionados mediante controladores que encapsulan las operaciones necesarias para su acceso. Sobre estos se implementaron los servicios de aplicación encargados de administrar los principales recursos del sistema, como las entradas y salidas digitales, las interfaces de comunicación y el reloj de tiempo real.

Las distintas funciones se ejecutan de forma concurrente mediante tareas de FreeRTOS, comunicadas principalmente a través de colas de mensajes y grupos de eventos. Esta organización permite desacoplar las solicitudes de su procesamiento y mantener el acceso al hardware dentro de las tareas correspondientes. Las interrupciones de los periféricos se utilizan para señalizar los eventos que requieren atención. En el nivel superior, \texttt{userTask} utiliza las interfaces proporcionadas por estos servicios para implementar la lógica específica del proceso productivo.

\subsection{Integración de las entradas digitales}

La integración de las entradas digitales se representa en la figura \ref{fig:integracion_entradas}. El flujo de información comienza en el circuito SCLT3-8BT8, encargado de acondicionar las señales provenientes del proceso y proporcionar su estado al microcontrolador mediante SPI. Las operaciones sobre esta interfaz se realizan a través de la HAL de STM32 y son encapsuladas por el driver de entradas, lo que evita que las capas superiores dependan de las particularidades de acceso al circuito integrado.

\begin{figure}[ht]
	\centering
	
	\caption{Integración hardware-software de las entradas digitales.}
	\label{fig:integracion_entradas}
\end{figure}

Sobre este driver se encuentra la tarea de entradas, encargada de realizar la adquisición y mantener disponible el estado de los canales. La API proporciona la función \texttt{app\_din\_read()}, mediante la cual la lógica implementada en \texttt{userTask} puede consultar las entradas del sistema. De esta forma, la información fluye desde las señales físicas hacia la lógica de control sin que esta última deba conocer el mecanismo de adquisición, la interfaz SPI ni las características particulares del SCLT3-8BT8.

\subsection{Integración de las salidas digitales}

El flujo asociado a las salidas digitales, presentado en la figura \ref{fig:integracion_salidas}, se desarrolla en sentido inverso al correspondiente a las entradas. Una decisión generada por la lógica de control en \texttt{userTask} se comunica mediante la función \texttt{app\_dout\_set()} de la API de salidas, que permite establecer el estado deseado sin acceder directamente al dispositivo físico.

\begin{figure}[ht]
	\centering
	
	\caption{Integración hardware-software de las salidas digitales.}
	\label{fig:integracion_salidas}
\end{figure}

La solicitud es procesada por la tarea de salidas y transferida al driver del VNI82\-00XP-32, que utiliza la interfaz SPI y los servicios de la HAL para efectuar la escritura sobre el circuito integrado. Este realiza finalmente el accionamiento de las cargas conectadas a las salidas digitales. Esta separación permite que la lógica del proceso opere sobre estados lógicos de salida, mientras que la transferencia de datos y el control del dispositivo permanecen encapsulados en las capas inferiores.

\subsection{Integración de la interfaz RS485}

A diferencia de los casos anteriores, la interfaz RS485 presenta un flujo de información bidireccional, como se muestra en la figura \ref{fig:integracion_rs485}. El transceptor SN65HVD\-82 constituye la interfaz física con el bus y se encuentra conectado a una UART del microcontrolador. La HAL proporciona los mecanismos de transmisión y recepción, mientras que el driver RS485 administra el intercambio de datos y la alternancia entre los modos de transmisión y recepción del transceptor.

\begin{figure}[ht]
	\centering
	
	\caption{Integración hardware-software de la interfaz RS485.}
	\label{fig:integracion_rs485}
\end{figure}

La tarea de RS485 actúa como intermediaria entre el driver y la lógica de aplicación y gestiona los datos recibidos y las solicitudes pendientes de transmisión. Las funciones \texttt{app\_rs485\_send()} y \texttt{app\_rs485\_receive()} proporcionan a \texttt{userTask} una interfaz bidireccional independiente de los detalles relacionados con la UART, las interrupciones y las señales de habilitación del transceptor. De este modo, la lógica del proceso puede intercambiar información con dispositivos externos mediante un servicio de comunicación uniforme.

\subsection{Integración de la interfaz de radiofrecuencia}

La integración de la comunicación inalámbrica, presentada en la figura \ref{fig:integracion_rf}, emplea el transceptor MRF24J40MA-I/RM conectado al microcontrolador mediante SPI. Las operaciones de acceso al dispositivo se realizan a través de la HAL y son encapsuladas por el driver MRF24J40, que proporciona las primitivas necesarias para la transmisión, recepción y gestión de los eventos generados por el transceptor.

\begin{figure}[ht]
	\centering
	
	\caption{Integración hardware-software de la interfaz de radiofrecuencia.}
	\label{fig:integracion_rf}
\end{figure}
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

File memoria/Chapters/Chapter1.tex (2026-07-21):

\chapter{Introducción general}
\label{Chapter1}

En este capítulo se presenta el contexto general del trabajo desarrollado y se introducen los conceptos fundamentales relacionados con los sistemas embebidos aplicados a automatización industrial. Se describe la motivación del trabajo, se revisan las principales tecnologías existentes y se establecen los objetivos definidos para el desarrollo del sistema propuesto.

%----------------------------------------------------------------------------------------

\section{Automatización industrial}
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

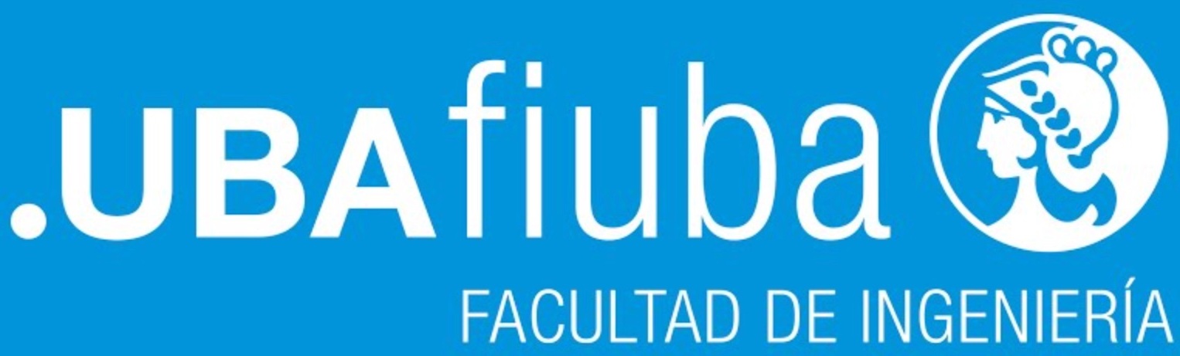
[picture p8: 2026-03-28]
hardware/dev/Imagenes/fiuba.jpg

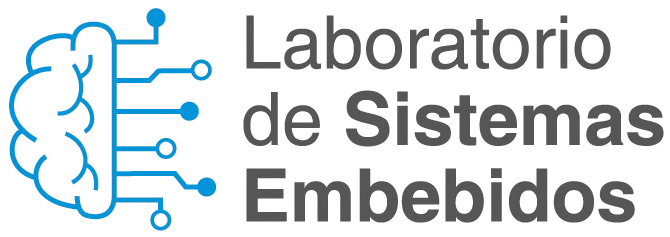
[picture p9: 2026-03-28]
hardware/dev/Imagenes/labse-uba.png

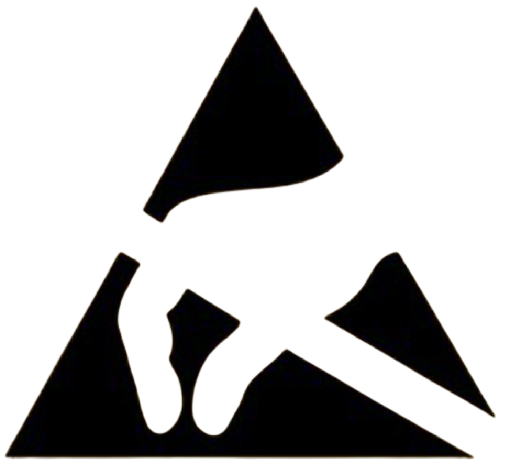
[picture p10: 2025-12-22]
hardware/dev/Imagenes/ESD sensitive.png

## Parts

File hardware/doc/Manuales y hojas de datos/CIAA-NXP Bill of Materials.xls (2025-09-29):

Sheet: ciaa-nxp
Componente | Cantidad por PCB | Referencia | Descripción | Código Digi-Key | Código Mouser | Cantidad para 100 PCBs | Costo unitario (USD FOB DigiKey) | Costo por PCB (USD FOB DigiKey)
BK-913 | 1 | BT1 | Soporte batería CR2032 | BK-913-ND | 534-3003 | 100 | $0.27000 | $0.27000 | BK-913-ND | 534-3003
15p | 2 | C79 C81 | Cap. Cerámico 0603 | 1276-1296-1-ND | 77-VJ0603A150JXACBC | 200 | $0.01210 | $0.02420 | 1276-1296-1-ND | 77-VJ0603A150JXACBC
18pF | 4 | C11 C12 C13 C14 | Cap. Cerámico 0603 | 399-1052-1-ND | 80-C0603C180J5G | 400 | $0.01540 | $0.06160 | 399-1052-1-ND | 80-C0603C180J5G
20p | 2 | C82 C83 | Cap. Cerámico 0603 | 1276-1187-1-ND | 81-GRM39C200J50 | 200 | $0.01380 | $0.02760 | 1276-1187-1-ND | 81-GRM39C200J50
22p | 2 | C84 C85 | Cap. Cerámico 0603 | 445-1273-1-ND | 80-C0603C220J5G | 200 | $0.01380 | $0.02760 | 445-1273-1-ND | 80-C0603C220J5G
470pF | 5 | C7 C38 C40 C44 C92 | Cap. Cerámico 0603 | 399-1075-1-ND | 80-C0603C471K5R | 500 | $0.01652 | $0.08260 | 399-1075-1-ND | 80-C0603C471K5R
1nF | 5 | C8 C36 C42 C91 C93 | Cap. Cerámico 0603 | 399-1082-1-ND | 80-C0603C102K5R | 500 | $0.01120 | $0.05600 | 399-1082-1-ND | 80-C0603C102K5R
10nF | 2 | C69 C88 | Cap. Cerámico 0603 | 399-1091-1-ND | 80-C0603C103K5R | 200 | $0.00900 | $0.01800 | 399-1091-1-ND | 80-C0603C103K5R
100nF | 61 | C2 C3 C4 C6 C9 C10 C15 C19 C20 C22 C23 C24 C25 C26 C27 C29 C30 C32 C33 C35 C37 C39 C41 C43 C45 C46 C47 C48 C49 C50 C51 C52 C53 C54 C55 C56 C57 C58 C59 C61 C62 C63 C64 C65 C66 C67 C70 C71 C72 C73 C74 C75 C76 C77 C86 C87 C89 C90 C94 C95 C96 | Cap. Cerámico 0603 | 399-5089-1-ND | 80-C0603C104K5R | 6100 | $0.00782 | $0.47702 | 399-5089-1-ND | 80-C0603C104K5R
1uF | 4 | C97 C98 C99 C100 | Cap. Cerámico 0603 | 399-7848-1-ND | 80-C0603C105K9P | 400 | $0.01836 | $0.07344 | 399-7848-1-ND | 80-C0603C105K9P
3.3uF | 1 | C80 | Cap. Cerámico SMD | 399-5502-1-ND | 80-C0603C335M9P | 100 | $0.01470 | $0.01470 | 399-5502-1-ND | 80-C0603C335M9P
10uF | 10 | C1 C5 C18 C31 C34 C60 C68 C78 C21 C28 | Cap. Tantáleo SMD | 399-10116-1-ND | 80-T491A106K0067280 | 1000 | $0.09200 | $0.92000 | 399-10116-1-ND | 80-T491A106K0067280
330uF/16V | 1 | C17 | Cap. Aluminio SMD | 493-9415-1-ND | 647-UCW1C331MNL1GS | 100 | $0.40610 | $0.40610 | 493-9415-1-ND | 647-UCW1C331MNL1GS
470uF/35V | 1 | C16 | Cap. Aluminio SMD | 493-3961-1-ND | 647-UCL1V471MNL1GS | 100 | $1.51700 | $1.51700 | 493-3961-1-ND | 647-UCL1V471MNL1GS
BAV199 | 6 | D9 D10 D11 D12 D46 D48 | Array de diodos SMD | BAV199LT1GOSCT-ND | 863-BAV199LT1G | 600 | $0.08646 | $0.51876 | BAV199LT1GOSCT-ND | 863-BAV199LT1G
PMEG3020EH | 3 | D1 D5 D45 | Diodo Schottky | 568-4129-1-ND | 771-PMEG3020EH-T/R | 300 | $0.20752 | $0.62256 | 568-4129-1-ND | 771-PMEG3020EH-T/R
MURS360T3G | 1 | D2 | Diodo 600V 3A | MURS360T3GOSCT-ND | 863-MURS360T3G | 100 | $0.46700 | $0.46700 | MURS360T3GOSCT-ND | 863-MURS360T3G
B540C-13-F | 1 | D3 | Diodo Schottky | B540C-FDICT-ND | 621-B540C-F | 100 | $0.73440 | $0.73440 | B540C-FDICT-ND | 621-B540C-F
LED red | 17 | D4 D13 D14 D15 D16 D17 D18 D19 D20 D21 D22 D23 D24 D33 D34 D35 D36 | LED Rojo 0603 | 1080-1400-1-ND | 78-VLMS1300-GS08 | 1700 | $0.07500 | $1.27500 | 1080-1400-1-ND | 78-VLMS1300-GS08
PSD12C | 3 | D6 D7 D8 | TVS | P6SMB12CAT3GOSCT-ND | 863-P6SMB12CAT3G | 300 | $0.23832 | $0.71496 | P6SMB12CAT3GOSCT-ND | 863-P6SMB12CAT3G
LL4148 | 4 | D27 D28 D30 D31 | Diodo SOD80 | LL4148FSCT-ND | 78-LL4148 | 400 | $0.01483 | $0.05932 | LL4148FSCT-ND | 78-LL4148
MMZ1608B601C | 11 | FB8 FB9 FB1 FB2 FB3 FB4 FB5 FB6 FB10 FB20 FB21 | EMI Filter 0603 | 445-2166-1-ND | 810-MMZ1608B601C | 1100 | $0.02508 | $0.27588 | 445-2166-1-ND | 810-MMZ1608B601C
BLM18KG221SN1 | 5 | FB7 FB11 FB14 FB15 FB16 | EMI Filter 0603 | 490-5255-1-ND | 81-BLM18KG221SN1D | 500 | $0.03484 | $0.17420 | 490-5255-1-ND | 81-BLM18KG221SN1D
BLM18BD470SN1 | 5 | FB12 FB13 FB17 FB18 FB19 | EMI Filter 0603 | 490-5211-1-ND | 81-BLM18BD470SN1D | 500 | $0.03484 | $0.17420 | 490-5211-1-ND | 81-BLM18BD470SN1D
PS2805C-4 | 2 | IC1 IC2 | Optoacoplador SMD AC. | PS2805C-4-A-ND | 551-PS2805C-4-F3-A | 200 | $2.09100 | $4.18200 | PS2805C-4-A-ND | 551-PS2805C-4-F3-A
DB9 | 1 | J3 | Conector DB9 macho para PCB Thru-hole | S9575-ND | 806-K22X-E9P-NJ | 100 | $0.54450 | $0.54450 | S9575-ND | 806-K22X-E9P-NJ
ZX62-AB-5PA | 1 | J6 | Conector micro USB tipo AB | H11635TR-ND | 798-ZX62-AB-5PA11 | 100 | $0.77440 | $0.77440 | H11635TR-ND | 798-ZX62-AB-5PA11
ZX62-B-5PA | 2 | J7 P16 | Conector micro USB tipo B | H11634CT-ND | 798-ZX62-B-5PA11 | 200 | $0.72600 | $1.45200 | H11634CT-ND | 798-ZX62-B-5PA11
TB_1X3 | 10 | J1 J8 J9 J10 J12 J13 J15 J16 J2 J4 | Bornes fijos x3 | ED2610-ND | FIX | 1000 | $0.26400 | $2.64000 | ED2610-ND | FIX
TB_1X2 | 5 | J11 J14 J17 J18 J19 | Bornes fijos x2 | ED2609-ND | FIX | 500 | $0.23100 | $1.15500 | ED2609-ND | FIX
JUMPER | 5 | JP1 JP2 JP4 JP5 JP6 | Jumper | 3M9580-ND | 649-68786-102LF | 500 | $0.04200 | $0.21000 | 3M9580-ND | 649-68786-102LF
PINES 1x40 | 1 | JP1 JP2 JP4 JP5 JP6 | Tira de pines 1x40 2.54mm | S1212EC-40-ND | 855-M20-9994045 | 100 | $0.47040 | $0.47040 | S1212EC-40-ND | 855-M20-9994045
G5V-2-DC5 | 4 | K1 K2 K3 K4 | Relé DPDT | Z767-ND | 653-G5V-2-DC5 | 400 | $1.98024 | $7.92096 | Z767-ND | 653-G5V-2-DC5
47uH | 1 | L2 | Inductor 3A SMD | SRN1060-470MCT-ND | 652-SRN1060-470M | 100 | $0.45000 | $0.45000 | SRN1060-470MCT-ND | 652-SRN1060-470M
BK1608HS220-T | 1 | L1 | Ferrite | MH1608-221YCT-ND | 963-BK1608HS220-T | 100 | $0.03480 | $0.03480 | MH1608-221YCT-ND | 963-BK1608HS220-T
SI-52003-F | 1 | P1 | Conector Ethernet con trafos y LEDs integrados con salidas PoE. | 380-1119-ND | Ver en ARROW | 100 | $4.68600 | $4.68600 | 380-1119-ND | FIX | Ver en ARROW!!!
PINES 2x40 | 2 | P2 P3 P12 P13 P14 P15 | Tira de pines 2x40 2.54mm | S2012EC-40-ND | 571-41037770 | 200 | $0.83370 | $1.66740 | S2012EC-40-ND | 571-41037770
Cortex-Debug | 1 | P8 | Conector 10 pines SMD 1.27mm | 952-1389-ND | 855-M50-3600542 | 100 | $0.88000 | $0.88000 | 952-1389-ND | 855-M50-3600542
USMF020 | 2 | PS1 PS2 | Polyswitch | MF-USMF020-2CT-ND | 652-MF-USMF020-2 | 200 | $0.22640 | $0.45280 | MF-USMF020-2CT-ND | 652-MF-USMF020-2
PBSS5240XF | 1 | Q1 | Transistor PNP 40V 2A | 568-10522-1-ND | 771-PBSS5240XF | 100 | $0.21770 | $0.21770 | 568-10522-1-ND | 771-PBSS5240XF
BC817-40 | 1 | Q14 | Transistor NPN 45V 0.5A | BC817-40LT3GOSCT-ND | 863-BC817-40LT3G | 100 | $0.07970 | $0.07970 | BC817-40LT3GOSCT-ND | 863-BC817-40LT3G
FQT13N06L | 4 | Q2 Q3 Q4 Q5 | MOSFET-N de potencia SMD | FQT13N06LTFCT-ND | 512-FQT13N06LTF | 400 | $1.00600 | $4.02400 | FQT13N06LTFCT-ND | 512-FQT13N06LTF
NDS7002A | 4 | Q6 Q7 Q11 Q12 | MOSFET-N SMD SOT-23 | NDS7002ACT-ND | 512-NDS7002A | 400 | $0.11542 | $0.46168 | NDS7002ACT-ND | 512-NDS7002A
0 | 17 | R7 R8 R9 R13 R14 R23 R24 R25 R26 R27 R28 R29 R30 R86 R87 R88 R89 | Resistor SMD 0603 | 311-0.0GRCT-ND | 71-CRCW0603-0-E3 | 1700 | $0.00204 | $0.03468 | 311-0.0GRCT-ND | 71-CRCW0603-0-E3
4.7 | 4 | R53 R61 R123 R128 | Resistor SMD 0603 | 311-4.7GRCT-ND | 71-CRCW0603-4.7 | 400 | $0.00348 | $0.01392 | 311-4.7GRCT-ND | 71-CRCW0603-4.7
22 | 3 | R10 R11 R12 | Resistor SMD 0603 | 311-22GRCT-ND | 71-CRCW060322R0FKEAH | 300 | $0.00348 | $0.01044 | 311-22GRCT-ND | 71-CRCW060322R0FKEAH
24.9 0.1% 25ppm/°C | 2 | R20 R83 | Resistor SMD 0603 | A109954CT-ND | 660-RN731JTTD24R9B25 | 200 | $0.28230 | $0.56460 | A109954CT-ND | 660-RN731JTTD24R9B25
50 | 4 | R3 R4 R5 R6 | Resistor SMD 0603 | 311-49.9HRCT-ND | 71-CRCW0603-50-E3 | 400 | $0.00456 | $0.01824 | 311-49.9HRCT-ND | 71-CRCW0603-50-E3
60 | 2 | R43 R46 | Resistor SMD 0603 | 311-59.0HRCT-ND | 71-CRCW0603-59-E3 | 200 | $0.00600 | $0.01200 | 311-59.0HRCT-ND | 71-CRCW0603-59-E3
100 | 4 | R51 R54 R57 R60 | Resistor SMD 0603 | 311-100GRCT-ND | 71-CRCW0603-100-E3 | 400 | $0.00204 | $0.00816 | 311-100GRCT-ND | 71-CRCW0603-100-E3
220 | 1 | R35 | Resistor SMD 0603 | 311-220GRCT-ND | 71-CRCW0603-220-E3 | 100 | $0.00450 | $0.00450 | 311-220GRCT-ND | 71-CRCW0603-220-E3
237 0.1% 25ppm/°C | 4 | R55 R62 R124 R129 | Resistor SMD 0603 | P237DBCT-ND | 667-ERA-3AEB2370V | 400 | $0.11000 | $0.44000 | P237DBCT-ND | 667-ERA-3AEB2370V
270 | 4 | R17 R18 R84 R44 | Resistor SMD 0603 | 311-270GRCT-ND | 71-CRCW0603-270-E3 | 400 | $0.00348 | $0.01392 | 311-270GRCT-ND | 71-CRCW0603-270-E3
330 | 8 | R131 R132 R133 R134 R135 R136 R137 R138 | Resistor SMD 0603 | 311-330GRCT-ND | 71-CRCW0603-330-E3 | 800 | $0.00278 | $0.02224 | 311-330GRCT-ND | 71-CRCW0603-330-E3
390 | 2 | R32 R39 | Resistor SMD 0603 | 311-390GRCT-ND | 71-CRCW0603-390-E3 | 200 | $0.00450 | $0.00900 | 311-390GRCT-ND | 71-CRCW0603-390-E3
1k | 2 | R22 R98 | Resistor SMD 0603 | 311-1.0KGRCT-ND | 71-CRCW0603-1.0K-E3 | 200 | $0.00450 | $0.00900 | 311-1.0KGRCT-ND | 71-CRCW0603-1.0K-E3
1k5 | 3 | R1 R42 R45 | Resistor SMD 0603 | 311-1.5KGRCT-ND | 71-CRCW0603-1.5K-E3 | 300 | $0.00348 | $0.01044 | 311-1.5KGRCT-ND | 71-CRCW0603-1.5K-E3
2.2k 250mW | 1 | R107 | Resistor SMD 1206 | P2.2KECT-ND | 667-ERJ-8GEYJ222V | 100 | $0.02100 | $0.02100 | P2.2KECT-ND | 667-ERJ-8GEYJ222V
2.2k | 11 | R99 R100 R141 R142 R144 R146 R148 R150 R152 R154 R104 | Resistor SMD 0603 | 311-2.2KGRCT-ND | 71-CRCW0603-2.2K-E3 | 1100 | $0.00348 | $0.03828 | 311-2.2KGRCT-ND | 71-CRCW0603-2.2K-E3
2.49k 0.1% 25ppm/°C | 1 | R105 | Resistor SMD 0603 | P2.49KDBCT-ND | 756-PCF0603R-2K49BT1 | 100 | $0.14340 | $0.14340 | P2.49KDBCT-ND | 756-PCF0603R-2K49BT1
3.3k 250mW | 8 | R65 R66 R67 R68 R69 R70 R71 R72 | Resistor SMD 1206 | P3.3KECT-ND | 667-ERJ-8GEYJ332V | 800 | $0.01152 | $0.09216 | P3.3KECT-ND | 667-ERJ-8GEYJ332V
4.7k | 13 | R34 R36 R37 R41 R47 R73 R74 R75 R76 R77 R78 R79 R140 | Resistor SMD 0603 | 311-4.7KGRCT-ND | 71-CRCW0603-4.7K-E3 | 1300 | $0.00278 | $0.03614 | 311-4.7KGRCT-ND | 71-CRCW0603-4.7K-E3
10k | 15 | R2 R15 R16 R48 R49 R85 R117 R118 R119 R120 R91 R101 R102 R103 R109 | Resistor SMD 0603 | 311-10KGRCT-ND | 71-CRCW0603-10K-E3 | 1500 | $0.00177 | $0.02655 | 311-10KGRCT-ND | 71-CRCW0603-10K-E3
12.1k 1% | 3 | R19 R95 R97 | Resistor SMD 0603 | 311-12.1KHRCT-ND | 71-CRCW0603-12.1K-E3 | 300 | $0.00456 | $0.01368 | 311-12.1KHRCT-ND | 71-CRCW0603-12.1K-E3
15k | 15 | R50 R52 R56 R58 R59 R63 R82 R121 R122 R125 R126 R127 R130 R93 R94 | Resistor SMD 0603 | RG16P15.0KBCT-ND | 756-PCF0603R-15KBT1 | 1500 | $0.07461 | $1.11915 | RG16P15.0KBCT-ND | 756-PCF0603R-15KBT1
33k | 1 | R80 | Resistor SMD 0603 | P33KDBCT-ND | 754-RG1608P-333-BT5 | 100 | $0.14340 | $0.14340 | P33KDBCT-ND | 754-RG1608P-333-BT5
100k | 21 | R21 R31 R64 R81 R106 R108 R111 R112 R115 R116 R143 R145 R147 R149 R151 R153 R155 R33 R38 R90 R92 | Resistor SMD 0603 | 311-100KGRCT-ND | 71-CRCW0603-100K-E3 | 2100 | $0.00204 | $0.04284 | 311-100KGRCT-ND | 71-CRCW0603-100K-E3
10M | 1 | R96 | Resistor SMD 0603 | 311-10MGRCT-ND | 71-CRCW0603-10M-E3 | 100 | $0.00450 | $0.00450 | 311-10MGRCT-ND | 71-CRCW0603-10M-E3
100 / 1/2W | 1 | R40 | Resistor SMD 2010 | CR2010-JW-101ELFCT-ND | 660-SG73P2ETTD1000F | 100 | $0.13780 | $0.13780 | CR2010-JW-101ELFCT-ND | 660-SG73P2ETTD1000F
SW_PUSH | 1 | SW1 | Tact switch SPST | 450-1792-1-ND | 612-TL3301BF260QG | 100 | $0.15820 | $0.15820 | 450-1792-1-ND | 612-TL3301BF260QG
MF-USMF005-2 | 1 | TH10 | Polyswitch 50mA | MF-USMF005-2CT-ND | 652-MF-USMF005-2 | 100 | $0.22640 | $0.22640 | MF-USMF005-2CT-ND | 652-MF-USMF005-2
PTS18126V300 | 1 | TH1 | Polyswitch 3A SMD | MF-SM300-2CT-ND | 504-PTS18126V300 | 100 | $0.41580 | $0.41580 | MF-SM300-2CT-ND | 504-PTS18126V300
PTS12066V100 | 6 | TH3 TH4 TH5 TH6 TH7 TH9 | Polyswitch 1A SMD | MF-USMF110-2CT-ND | 504-PTS12066V100 | 600 | $0.16800 | $1.00800 | MF-USMF110-2CT-ND | 504-PTS12066V100
MF-MSMF030-2 | 1 | TH8 | Polyswitch 0.3A SMD | MF-MSMF030-2CT-ND | 652-MF-MSMF030-2 | 100 | $0.24260 | $0.24260 | MF-MSMF030-2CT-ND | 652-MF-MSMF030-2
DLW21HN900SQ2 | 3 | TR1 TR2 TR3 | Choke USB | SRF2012-900YCT-ND | 81-DLW21HN900SQ2L | 300 | $0.29924 | $0.89772 | SRF2012-900YCT-ND | 81-DLW21HN900SQ2L
LAN8720A-CP | 1 | U1 | Ethernet PHY | LAN8720A-CP-CT-ND | 886-LAN8720A-CP-TR | 100 | $0.76000 | $0.76000 | LAN8720A-CP-CT-ND | 886-LAN8720A-CP-TR
ST3232E | 1 | U6 | Transceiver RS232 16-TSSOP | 497-6538-1-ND | 511-ST3232EC | 100 | $0.71820 | $0.71820 | 497-6538-1-ND | 511-ST3232EC
TJA1040 | 1 | U7 | Transceiver CAN 8-SOIC | 568-10289-1-ND | 771-TJA1040T/CM118 | 100 | $0.92330 | $0.92330 | 568-10289-1-ND | 771-TJA1040T/CM118
PESD1CAN | 1 | U8 | TVS para CAN | 568-4032-1-ND | 771-PESD1CAN-T/R | 100 | $0.25370 | $0.25370 | 568-4032-1-ND | 771-PESD1CAN-T/R
MIC2025-2YM | 1 | U10 | Switch USB 8-TSSOP | 576-1058-ND | 998-MIC2025-2YMTR | 100 | $0.76710 | $0.76710 | 576-1058-ND | 998-MIC2025-2YMTR
MCP6024 | 1 | U11 | OpAmp 14-TSSOP | MCP6024-I/ST-ND | 579-MCP6024-I/ST | 100 | $1.44000 | $1.44000 | MCP6024-I/ST-ND | 579-MCP6024-I/ST
24AA1025 | 1 | U12 | EEPROM 1Mb | 24AA1025-I/SN-ND | 579-24AA1025T-I/SN | 100 | $2.67500 | $2.67500 | 24AA1025-I/SN-ND | 579-24AA1025T-I/SN
24AA025E48 | 1 | U13 | EEPROM 2kb | 24AA025E48-I/SN-ND | 579-24AA025E48T-I/SN | 100 | $0.26520 | $0.26520 | 24AA025E48-I/SN-ND | 579-24AA025E48T-I/SN
TXB0108 | 1 | U14 | Buffer bidireccional 20-TSSOP | 296-21527-1-ND | 595-TXB0108PWR | 100 | $1.67040 | $1.67040 | 296-21527-1-ND | 595-TXB0108PWR
IS42S16800F-7TL | 1 | U15 | SDRAM 128Mb 54-TSOP | IS42S16800F-7TL-TR | 870-IS42S16800F-7TL | 100 | $3.53760 | $3.53760 | IS42S16800F-7TL-TR | 870-IS42S16800F-7TL
FT2232H | 1 | U17 | USB IC 64-LQFP | 768-1024-1-ND | 895-FT2232HL | 100 | $5.40000 | $5.40000 | 768-1024-1-ND | 895-FT2232HL
LM358 | 1 | U18 | Dual OpAmp | LM358DGOS-ND | 863-LM358DG | 100 | $0.26050 | $0.26050 | LM358DGOS-ND | 863-LM358DG
93C46 | 1 | U19 | EEPROM 8-TSSOP, MicroWire | AT93C46DN-SH-B-ND | 579-93C46A-I/SN | 100 | $0.20860 | $0.20860 | AT93C46DN-SH-B-ND | 579-93C46A-I/SN
SN75HVD1176DR | 1 | U5 | Transceiver RS485/Profibus 8-SOIC | SN75HVD1176DR | 595-SN75HVD1176DR | 100 | $3.10170 | $3.10170 | SN75HVD1176DR | 595-SN75HVD1176DR
SI502 | 1 | U2 | Oscilador 50MHz SMD, 30ppm | 535-10829-1-ND | 815-ASV-50.000M-EK-T | 100 | $1.00170 | $1.00170 | 535-10829-1-ND | 815-ASV-50.000M-EK-T
LM2596-5.0 | 1 | U3 | Regulador 5V TO263-5 | LM2596SX-5.0/NOPBCT-ND | 926-LM2596SX-5.0NOPB | 100 | $3.41820 | $3.41820 | LM2596SX-5.0/NOPBCT-ND | 926-LM2596SX-5.0NOPB
NCP1117ST33T3G | 1 | U4 | Regulador 3.3V SOT223 | NCP1117ST33T3GOSCT-ND | 863-NCP1117ST33T3G | 100 | $0.31270 | $0.31270 | NCP1117ST33T3GOSCT-ND | 863-NCP1117ST33T3G
PRTR5V0U2X | 1 | U9 | TVS para USB | 568-4140-1-ND | 771-PRTR5V0U2X-T/R | 100 | $0.35780 | $0.35780 | 568-4140-1-ND | 771-PRTR5V0U2X-T/R
LPC4337JBD144 rev. A | 1 | U16 | Microcontrolador LPC4337 Rev. A | 568-10159-ND | 771-LPC4337JBD144E | 100 | $11.05000 | $11.05000 | 568-10159-ND | 771-LPC4337JBD144E
S25FL127SABNFI101 | 1 | U20 | Flash qSPI 128Mb WSON-8 | 1274-1046-ND | 797-25FL127SABNFI101 | 100 | $2.12000 | $2.12000 | 1274-1046-ND | 797-25FL127SABNFI101
MCP1416T | 4 | U21 U22 U23 U24 | Driver MOSFET | MCP1416T-E/OTCT-ND | 579-MCP1416T-E/OT | 400 | $0.47000 | $1.88000 | MCP1416T-E/OTCT-ND | 579-MCP1416T-E/OT
32.768K | 1 | X1 | Cristal SMD | 535-9166-1-ND | 815-ABS25-32.768KHZT | 100 | $0.43200 | $0.43200 | 535-9166-1-ND | 815-ABS25-32.768KHZT
12MHz | 2 | X2 X3 | Cristal SMD | SER3683CT-ND | 732-FA-238V12MB-W3 | 200 | $0.80000 | $1.60000 | SER3683CT-ND | 732-FA-238V12MB-W3
SMBJ20CA | 4 | ZA2 ZA3 ZA4 ZA5 | TVS SMD | P6SMB20CAT3GOSCT-ND | 576-P6SMB20CA | 400 | $0.24968 | $0.99872 | P6SMB20CAT3GOSCT-ND | 576-P6SMB20CA
P6SMB33CA | 1 | ZA1 | TVS SMD | P6SMB33CA-E3/52GICT-ND | 576-P6SMB33CA | 100 | $0.22992 | $0.22992 | P6SMB33CA-E3/52GICT-ND | 576-P6SMB33CA
SMAZ5V6 | 1 | ZA14 | Zener SMD | MMSZ5V6T1GOSCT-ND | 78-BZT52C5V6-E3-08 | 100 | $0.12470 | $0.12470 | MMSZ5V6T1GOSCT-ND | 78-BZT52C5V6-E3-08
 |  |  |  |  |  | Costo de componentes FOB: |  | $92.74128
 |  |  |  |  |  |  | Envío: | $40.00
 |  |  |  |  |  | Impuestos de importación (%): |  | 30%
 |  |  |  |  |  |  | Impuestos de importación ($): | $27.94238
 |  |  |  |  |  |  | Montaje: | tbd
 |  |  |  |  |  |  | PCB: | tbd
 |  |  |  |  |  |  | Gabinete: | tbd
 |  |  |  |  | Costo por CIAA, fabricando 100 CIAAs: |  |  | $121.08
Opción: CIAA con Borneras Desmontables
TBP_1X8 | 4 |  | Borneras enchufables 8P (bornes) | ED1723-ND | 538-39530-0008 | 400 | $3.03624 | $12.14496 | ED1723-ND | 538-39530-0008
TBP_1X4 | 2 |  | Borneras enchufables 4P (bornes) | ED2910-ND | 538-39530-0004 | 200 | $1.19700 | $2.39400 | ED2910-ND | 538-39530-0004
TBH_1X8 | 4 |  | Borneras enchufables 8P (header) | 277-1101-ND | 651-1757307 | 400 | $1.86740 | $7.46960 | 277-1101-ND | 651-1757307
TBH_1X4 | 2 |  | Borneras enchufables 4P (header) | A98067-ND | 571-282814-4 | 200 | $0.79400 | $1.58800 | A98067-ND | 571-282814-4
 |  |  |  |  | Costo de componentes FOB: |  |  | $112.54284
 |  |  |  |  |  | Diferencia usando bornes fijos: |  | $19.80156
 |  |  |  |  |  |  | Impuestos de importación ($): | $33.88285
 |  |  |  |  | Costo por CIAA, fabricando 100 CIAAs: |  |  | $146.83

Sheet: ciaa-nxp-industrial
Componente | Cantidad por PCB | Referencia | Descripción | Código Digi-Key | Código Mouser | Cantidad para 100 PCBs | Costo unitario (USD FOB DigiKey) | Costo por PCB (USD FOB DigiKey)
LAN8720AI-CP | 1 | U1 | Ethernet PHY | LAN8720AI-CP-TR-ND | 886-LAN8720AI-CP-TR | 100 |  | $0.00000 | LAN8720AI-CP-TR-ND | 886-LAN8720AI-CP-TR
ST3232E | 1 | U6 | Transceiver RS232 16-TSSOP | 497-6536-1-ND | 511-ST3232EB | 100 |  | $0.00000 | 497-6536-1-ND | 511-ST3232EB
TXB0108 | 1 | U14 | Buffer bidireccional 20-TSSOP | 296-21527-1-ND | 595-TXB0108PWR | 100 |  | $0.00000 | 296-21527-1-ND | 595-TXB0108PWR
IS42S16400F | 1 | U15 | SDRAM 64Mb 54-TSOP | IS42S16400F-7TLI | 870-42S16400F-7TLI | 100 |  | $0.00000 | IS42S16400F-7TLI | 870-42S16400F-7TLI
LM258 | 1 | U18 | Dual OpAmp | LM258DGOS-ND | 863-LM258DG | 100 |  | $0.00000 | LM258DGOS-ND | 863-LM258DG
SN65HVD1176DR | 1 | U5 | Transceiver RS485/Profibus 8-SOIC | 296-26337-1-ND | 595-SN65HVD1176DR | 100 |  | $0.00000 | 296-26337-1-ND | 595-SN65HVD1176DR
SI502 | 1 | U2 | Oscilador 50MHz SMD 30ppm | 535-10829-1-ND | 815-ASV-50.000M-NK-T | 100 |  | $0.00000 | 535-10829-1-ND | 815-ASV-50.000M-NK-T
NCV1117ST33T3G | 1 | U4 | Regulador 3.3V SOT223 | NCV1117ST33T3GOSCT-ND | 863-NCV1117ST33T3G | 100 |  | $0.00000 | NCV1117ST33T3GOSCT-ND | 863-NCV1117ST33T3G

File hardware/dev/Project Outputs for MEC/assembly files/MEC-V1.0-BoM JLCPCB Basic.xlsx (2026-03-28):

Designator | JLCPCB Basic Part # | Description
C1, C2, C3, C6, C7, C8, C9, C10, C17, C18, C19, C20, C21, C22, C23, C24 | C1729 | Multilayer Ceramic Capacitors MLCC - SMD/SMT 100 V 0.022 uF X7R 0805 10%
C4, C28, C41, C42, C43, C45, C46, C48, C49, C50, C51, C54, C57, C64, C65, C66, C67, C72, C73, C74, C75, C76 | C307331 | Multilayer Ceramic Capacitors MLCC - SMD/SMT 50 V 0.1uF X7R 0402 10%
C5 | C1739 | Multilayer Ceramic Capacitors MLCC - SMD/SMT 100 V 0.033 uF X7R 0805 10%
C11, C12, C13, C14, C25, C34, C35, C36, C37 | C1562 | Multilayer Ceramic Capacitors MLCC - SMD/SMT 50 V 33 pF C0G 0402 1%
C15, C52 | C52923 | Multilayer Ceramic Capacitors MLCC - SMD/SMT 50V 1uF X5R 0402 10% HI CV
C16, C33, C38, C39, C40 | C1546 | Multilayer Ceramic Capacitors MLCC - SMD/SMT 50 V 100pF X7R 0402 10%
C26 | C1532 | Multilayer Ceramic Capacitors MLCC - SMD/SMT 50 V 0.022uF X7R 0402 10%
C27, C29, C30 | C15195 | Multilayer Ceramic Capacitors MLCC - SMD/SMT 50 V 0.01uF X7R 0402 10%
C31 | C47339 | Multilayer Ceramic Capacitors MLCC - SMD/SMT 50 V 0.470uF X7R 0402 10%
C32, C71 | C23733 | Multilayer Ceramic Capacitors MLCC - SMD/SMT 10V 4.7uF X5R 0402 10% HI CV
C53 | C1537 | Multilayer Ceramic Capacitors MLCC - SMD/SMT 50 V 470pF X7R 0402 10%
C55, C56, C68, C69, C70, C79 | C1547 | Multilayer Ceramic Capacitors MLCC - SMD/SMT 50 V 12 pF C0G 0402 1%
C58, C63 | C440198 | Multilayer Ceramic Capacitors MLCC - SMD/SMT 16V 10uF X5R 0805 10%
C60 | C9196 | Multilayer Ceramic Capacitors MLCC - SMD/SMT 2kV 1000pF X7R 1206 10%
C61, C62 | C1779 | Multilayer Ceramic Capacitors MLCC - SMD/SMT 50V 4.7uF X5R 0805 10%
C77, C78 | C12530 | Multilayer Ceramic Capacitors MLCC - SMD/SMT 25V 2.2uF X5R 0402 10% HI CV
D1, D2, D3, D4, D5, D6, D7, D8, D13, D14, D15, D16, D17, D18, D19, D20, D22, D36 | C125094 | Standard Single Color LEDs 0603 Green
D9, D10, D11, D34 | C2286 | Standard Single Color LEDs 0603 Red
D12, D28 | C7502706 | Schottky Diodes & Rectifiers 350mA 40V SOD123
D21 | C7420375 | ESD Protection Diodes / TVS Diodes SOT-23 7V400W Low Capacitance
D23, D35 | C89811 | Standard Single Color LEDs 0603 Yellow
D24 | C85364 | ESD Protection Diodes / TVS Diodes Low Cap ESD Protect
D25, D26 | C14996 | Schottky Diodes & Rectifiers 2A 100V SMA
D27 | C19077544 | ESD Protection Diodes / TVS Diodes 400W 26V 5% Bi-Directional
D29, D30, D31, D32, D33, D37 | C20615801 | ESD Protection Diodes / TVS Diodes UNIDIRECTIONAL 3.3V ESD PR
F1 | C136354 | Surface Mount Fuses 1206 high-current met-foil. 10A
J9, J10, J11, J12, J15, J16, J17, J18, J24 | C8475 | Pluggable Terminal Blocks 2 Pos 5.08mm pitch Through Hole Header
J20 | C8483 | Pluggable Terminal Blocks 3 Pos 5.08mm pitch Through Hole Header
J22 | C34677 | Modular Ethernet Connector Jack (Female) 1x1 Shielded Through Hole With LEDs With Magnetics
J26 | C7465995 | Male straight header, 2 row, 14 positions, 1.27mm pitch, SMD
J27 | C192300 | Male straight header, 2 row, 8 positions, 2.54mm pitch, SMD
L1 | C83471 | Power Inductors - SMD 100uH 0.42A 1.6Ohms
L2 | C1002 | Ferrite Beads 600 OHM 25% Alternate Sizing Guide Below
L4 | C878356 | Common Mode Chokes / Filters WE-SL2 SMD Sectional 2x10uH 1600mA
R1, R2, R5, R6, R7, R8, R9, R11 | C17520 | Thick Film Resistors - SMD General Purpose Chip Resistor 0805, 2.2kOhms, 1%, 1/8W
R3 | C17513 | Thick Film Resistors - SMD General Purpose Chip Resistor 0805, 1kOhms, 1%, 1/8W
R4 | C25794 | Thick Film Resistors - SMD General Purpose Chip Resistor 0402, 51kOhms, 1%, 1/16W
R10 | C25756 | Thick Film Resistors - SMD General Purpose Chip Resistor 0402, 15kOhms, 1%, 1/16W
R12 | C17514 | Thick Film Resistors - SMD General Purpose Chip Resistor 0805, 1MOhms, 1%, 1/8W
R13 | C17840 | Thick Film Resistors - SMD General Purpose Chip Resistor 0805, 82 kOhms, 1%, 1/8W
R14, R15, R16, R17, R21, R25, R26, R27, R28 | C25091 | Thick Film Resistors - SMD General Purpose Chip Resistor 0402, 220Ohms, 1%, 1/16W
R18, R19, R20, R29, R30, R31, R35, R36, R37, R38, R39 | C25130 | Thick Film Resistors - SMD General Purpose Chip Resistor 0402, 680Ohms, 1%, 1/16W
R22 | C22975 | Thick Film Resistors - SMD General Purpose Chip Resistor 0603, 2kOhms, 1%, 1/10W
R23 | C25804 | Thick Film Resistors - SMD General Purpose Chip Resistor 0603, 10kOhms, 1%, 1/10W
R24 | C22978 | Thick Film Resistors - SMD General Purpose Chip Resistor 0603, 3.3kOhms, 1%, 1/10W
R32, R33, R34, R40, R43, R44, R53, R54, R55, R56, R65, R72, R79 | C25744 | Thick Film Resistors - SMD General Purpose Chip Resistor 0402, 10kOhms, 1%, 1/16W
R41, R45 | C844598 | Thick Film Resistors - SMD High Power Chip Resistor 0805, 10Ohms, 1%, 1/2W
R42 | C25079 | Thick Film Resistors - SMD General Purpose Chip Resistor 0402, 120Ohms, 1%, 1/16W
R46, R47 | C11702 | Thick Film Resistors - SMD General Purpose Chip Resistor 0402, 1kOhms, 1%, 1/16W
R49, R50, R51, R52 | C25120 | Thick Film Resistors - SMD General Purpose Chip Resistor 0402, 49.9Ohms, 1%, 1/16W
R57 | C25867 | Thick Film Resistors - SMD General Purpose Chip Resistor 0402, 1.5kOhms, 1%, 1/16W
R58, R59, R64, R67 | C25105 | Thick Film Resistors - SMD General Purpose Chip Resistor 0402, 33Ohms, 1%, 1/16W
R68 | C25752 | Thick Film Resistors - SMD General Purpose Chip Resistor 0402, 12.1kOhms, 1%, 1/16W
R71, R73, R74, R75, R76, R77 | C25104 | Thick Film Resistors - SMD General Purpose Chip Resistor 0402, 330Ohms, 1%, 1/16W
R78 | C25741 | Thick Film Resistors - SMD General Purpose Chip Resistor 0402, 100kOhms, 1%, 1/16W
R80, R82, R84 | C17168 | Thick Film Resistors - SMD General Purpose Chip Resistor 0402, 0Ohms, 1%, 1/16W
S1 | C720477 | Tactile Switches SMD OFF - (ON)
U3 | C73631 | RS-485 Interface IC 5V-Supply
U4, U10 | C528656 | Digital Isolators 3.75 kV 5 forward & 1 reverse 6-channel isolator
U5 | C621424 | Ethernet PHY transceiver 10/100-Mbps
U6 | C36395 | LDO Voltage Regulators 3.3V 0.8A Positive
U9 | C20619634 | ARM Microcontrollers - MCU Arm Cortex-M33 32-bit 250 MHz 2 Mbytes Flash 640KB RAM I3C, DCMI, Ethernet, SMPS
Y1, Y3 | C9006 | Crystals 25MHz 12pF 20ppm -40C +125C
Y2 | C32346 | Crystals 32.768KHz 20ppm 12.5pF -40C +85C

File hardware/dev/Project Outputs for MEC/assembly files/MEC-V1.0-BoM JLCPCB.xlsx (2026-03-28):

Designator | JLCPCB Part # | Description
C1, C2, C3, C6, C7, C8, C9, C10, C17, C18, C19, C20, C21, C22, C23, C24 | C107137 | Multilayer Ceramic Capacitors MLCC - SMD/SMT 100 V 0.022 uF X7R 0805 10%
C4, C28, C41, C42, C43, C45, C46, C48, C49, C50, C51, C54, C57, C64, C65, C66, C67, C72, C73, C74, C75, C76 | C105882 | Multilayer Ceramic Capacitors MLCC - SMD/SMT 50 V 0.1uF X7R 0402 10%
C5 | C327114 | Multilayer Ceramic Capacitors MLCC - SMD/SMT 100 V 0.033 uF X7R 0805 10%
C11, C12, C13, C14, C25, C34, C35, C36, C37 | C107005 | Multilayer Ceramic Capacitors MLCC - SMD/SMT 50 V 33 pF C0G 0402 1%
C15, C52 | C7500380 | Multilayer Ceramic Capacitors MLCC - SMD/SMT 50V 1uF X5R 0402 10% HI CV
C16, C33, C38, C39, C40 | C281751 | Multilayer Ceramic Capacitors MLCC - SMD/SMT 50 V 100pF X7R 0402 10%
C26 | C107026 | Multilayer Ceramic Capacitors MLCC - SMD/SMT 50 V 0.022uF X7R 0402 10%
C27, C29, C30 | C60133 | Multilayer Ceramic Capacitors MLCC - SMD/SMT 50 V 0.01uF X7R 0402 10%
C31 | C513552 | Multilayer Ceramic Capacitors MLCC - SMD/SMT 50 V 0.470uF X7R 0402 10%
C32, C71 | C326586 | Multilayer Ceramic Capacitors MLCC - SMD/SMT 10V 4.7uF X5R 0402 10% HI CV
C53 | C106207 | Multilayer Ceramic Capacitors MLCC - SMD/SMT 50 V 470pF X7R 0402 10%
C55, C56, C68, C69, C70, C79 | C326662 | Multilayer Ceramic Capacitors MLCC - SMD/SMT 50 V 12 pF C0G 0402 1%
C58, C63 | C89827 | Multilayer Ceramic Capacitors MLCC - SMD/SMT 16V 10uF X5R 0805 10%
C60 | C23631 | Multilayer Ceramic Capacitors MLCC - SMD/SMT 2kV 1000pF X7R 1206 10%
C61, C62 | C2897302 | Multilayer Ceramic Capacitors MLCC - SMD/SMT 50V 4.7uF X5R 0805 10%
C77, C78 | C723363 | Multilayer Ceramic Capacitors MLCC - SMD/SMT 25V 2.2uF X5R 0402 10% HI CV
D1, D2, D3, D4, D5, D6, D7, D8, D13, D14, D15, D16, D17, D18, D19, D20, D22, D36 | C125094 | Standard Single Color LEDs 0603 Green
D9, D10, D11, D34 | C94869 | Standard Single Color LEDs 0603 Red
D12, D28 | C181204 | Schottky Diodes & Rectifiers 350mA 40V SOD123
D21 | C5122012 | ESD Protection Diodes / TVS Diodes SOT-23 7V400W Low Capacitance
D23, D35 | C125095 | Standard Single Color LEDs 0603 Yellow
D24 | C558419 | ESD Protection Diodes / TVS Diodes Low Cap ESD Protect
D25, D26 | C14996 | Schottky Diodes & Rectifiers 2A 100V SMA
D27 | C173517 | ESD Protection Diodes / TVS Diodes 400W 26V 5% Bi-Directional
D29, D30, D31, D32, D33, D37 | C19829399 | ESD Protection Diodes / TVS Diodes UNIDIRECTIONAL 3.3V ESD PR
F1 | C136354 | Surface Mount Fuses 1206 high-current met-foil. 10A
J9, J10, J11, J12, J15, J16, J17, J18, J24 | C8475 | Pluggable Terminal Blocks 2 Pos 5.08mm pitch Through Hole Header
J20 | C8483 | Pluggable Terminal Blocks 3 Pos 5.08mm pitch Through Hole Header
J22 | C34677 | Modular Ethernet Connector Jack (Female) 1x1 Shielded Through Hole With LEDs With Magnetics
J26 | C7465995 | Male straight header, 2 row, 14 positions, 1.27mm pitch, SMD
J27 | C192300 | Male straight header, 2 row, 8 positions, 2.54mm pitch, SMD
L1 | C83471 | Power Inductors - SMD 100uH 0.42A 1.6Ohms
L2 | C76886 | Ferrite Beads 600 OHM 25% Alternate Sizing Guide Below
L4 | C878356 | Common Mode Chokes / Filters WE-SL2 SMD Sectional 2x10uH 1600mA
R1, R2, R5, R6, R7, R8, R9, R11 | C114561 | Thick Film Resistors - SMD General Purpose Chip Resistor 0805, 2.2kOhms, 1%, 1/8W
R3 | C95781 | Thick Film Resistors - SMD General Purpose Chip Resistor 0805, 1kOhms, 1%, 1/8W
R4 | C107229 | Thick Film Resistors - SMD General Purpose Chip Resistor 0402, 51kOhms, 1%, 1/16W
R10 | C114761 | Thick Film Resistors - SMD General Purpose Chip Resistor 0402, 15kOhms, 1%, 1/16W
R12 | C107700 | Thick Film Resistors - SMD General Purpose Chip Resistor 0805, 1MOhms, 1%, 1/8W
R13 | C137489 | Thick Film Resistors - SMD General Purpose Chip Resistor 0805, 82 kOhms, 1%, 1/8W
R14, R15, R16, R17, R21, R25, R26, R27, R28 | C112291 | Thick Film Resistors - SMD General Purpose Chip Resistor 0402, 220Ohms, 1%, 1/16W
R18, R19, R20, R29, R30, R31, R35, R36, R37, R38, R39 | C137948 | Thick Film Resistors - SMD General Purpose Chip Resistor 0402, 680Ohms, 1%, 1/16W
R22 | C105576 | Thick Film Resistors - SMD General Purpose Chip Resistor 0603, 2kOhms, 1%, 1/10W
R23 | C98220 | Thick Film Resistors - SMD General Purpose Chip Resistor 0603, 10kOhms, 1%, 1/10W
R24 | C108078 | Thick Film Resistors - SMD General Purpose Chip Resistor 0603, 3.3kOhms, 1%, 1/10W
R32, R33, R34, R40, R43, R44, R53, R54, R55, R56, R65, R72, R79 | C60490 | Thick Film Resistors - SMD General Purpose Chip Resistor 0402, 10kOhms, 1%, 1/16W
R41, R45 | C844598 | Thick Film Resistors - SMD High Power Chip Resistor 0805, 10Ohms, 1%, 1/2W
R42 | C114758 | Thick Film Resistors - SMD General Purpose Chip Resistor 0402, 120Ohms, 1%, 1/16W
R46, R47 | C106235 | Thick Film Resistors - SMD General Purpose Chip Resistor 0402, 1kOhms, 1%, 1/16W
R49, R50, R51, R52 | C87044 | Thick Film Resistors - SMD General Purpose Chip Resistor 0402, 49.9Ohms, 1%, 1/16W
R57 | C114759 | Thick Film Resistors - SMD General Purpose Chip Resistor 0402, 1.5kOhms, 1%, 1/16W
R58, R59, R64, R67 | C138002 | Thick Film Resistors - SMD General Purpose Chip Resistor 0402, 33Ohms, 1%, 1/16W
R68 | C132157 | Thick Film Resistors - SMD General Purpose Chip Resistor 0402, 12.1kOhms, 1%, 1/16W
R71, R73, R74, R75, R76, R77 | C105875 | Thick Film Resistors - SMD General Purpose Chip Resistor 0402, 330Ohms, 1%, 1/16W
R78 | C60491 | Thick Film Resistors - SMD General Purpose Chip Resistor 0402, 100kOhms, 1%, 1/16W
R80, R82, R84 | C106231 | Thick Film Resistors - SMD General Purpose Chip Resistor 0402, 0Ohms, 1%, 1/16W
S1 | C3012022 | Tactile Switches SMD OFF - (ON)
U3 | C73631 | RS-485 Interface IC 5V-Supply
U4, U10 | C528656 | Digital Isolators 3.75 kV 5 forward & 1 reverse 6-channel isolator
U5 | C621424 | Ethernet PHY transceiver 10/100-Mbps
U6 | C36395 | LDO Voltage Regulators 3.3V 0.8A Positive
U9 | C20619634 | ARM Microcontrollers - MCU Arm Cortex-M33 32-bit 250 MHz 2 Mbytes Flash 640KB RAM I3C, DCMI, Ethernet, SMPS
Y1, Y3 | C91750 | Crystals 25MHz 12pF 20ppm -40C +125C
Y2 | C32346 | Crystals 32.768KHz 20ppm 12.5pF -40C +85C

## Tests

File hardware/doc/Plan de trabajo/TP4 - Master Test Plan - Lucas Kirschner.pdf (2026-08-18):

# Sistema modular para monitoreo y control industrial con comunicación inalámbrica y capacidades de automatización embebida

## Master Test Plan

## Lucas Sebastián Kirschner

## (kirschnerlucas1@gmail.com)

01/10/2025

## versión A

## Esta obra está bajo una

## Licencia Creative Commons Atribución

## 4.0 Internacional. (http://creativecommons.org/licenses/by/4.0/)

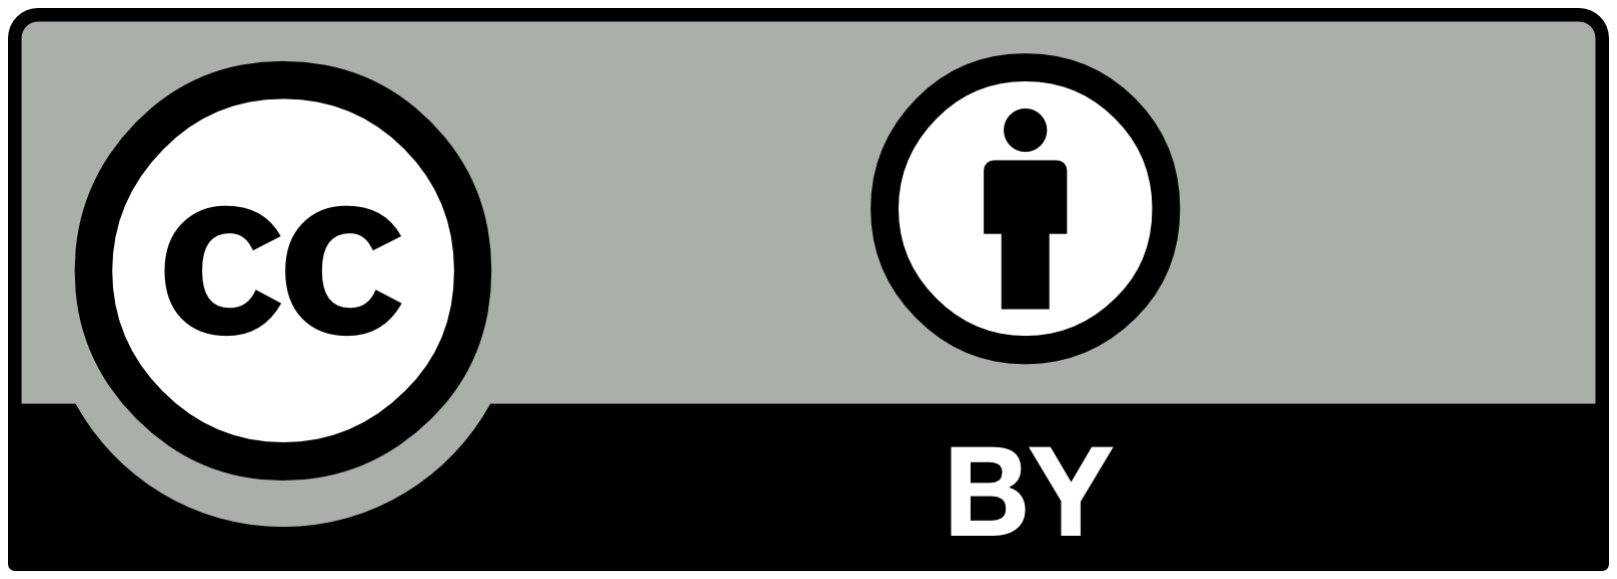
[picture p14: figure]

Sistema modular para monitoreo y control industrial con comunicación inalámbrica y capacidades de automatización embebida
Master Test Plan
SCMCII-MTP-0001 versión A

## Historial de cambios

Versión | Fecha | Descripción | Autor | Revisores
A | 01/10/25 | Versión Original | L. Kirschner
B | 20/10/25 | Se corrige sección 4.5 | L. Kirschner

Esta obra está bajo una Licencia Creative
Commons Atribución 4.0 Internacional. (http://creativecommons.org/licenses/by/4.0/) | 2/12

SCMCII-MTP-0001 versión A

## Índice de contenido

1. Introducción | 4
1.1. Propósito | 4
1.2. Descripción general del sistema | 4
1.3. Contenidos del documento | 6
2. Asignaciones | 6
2.1. Responsable | 6
2.2. Contratista | 6
2.3. Alcance | 6
2.4. Objetivos | 6
2.5. Precondiciones | 7
3. Bases del test | 7
4. Estrategia general del test | 8
4.1. Características de calidad | 8
4.2. Asignación de características a niveles de prueba | 9
4.3. División del sistema en subsistemas | 10
4.4. Determinación de la importancia relativa de los subsistemas | 10
4.5. Determinación de la importancia relativa de los subsistemas | 11

SCMCII-MTP-0001 versión A

## 1. Introducción

## 1.1. Propósito

Este documento especifica el Master Test Plan (MTP) del software del Trabajo Final “Sistema modular para monitoreo y control industrial con comunicación inalámbrica y capacidades de automatización embebida”. El MTP define qué se prueba, quién y cuándo lo prueba y cómo se prueba, integrando tipos y niveles de prueba con una planificación realista y comunicable a las áreas involucradas.

## 1.2. Descripción general del sistema

El sistema propuesto es distribuido: una estación central coordina múltiples estaciones remotas para adquisición de datos de campo, control de actuadores y comunicación eficiente donde el cableado es costoso o impracticable. La solución enfatiza flexibilidad, escalabilidad y adaptabilidad para PyMEs con baja infraestructura de conectividad.
La Figura 1 muestra el diagrama en bloques del sistema y resume la arquitectura distribuida propuesta. Se distinguen claramente la estación central, con un microcontrolador de altas prestaciones, las interfaces de comunicación (Ethernet e inalámbrica), las opciones de alimentación (PoE o red eléctrica) y las estaciones remotas, dotadas de entradas y salidas digitales industriales, interfaz inalámbrica y comunicación serie robusta para dispositivos de campo.

SCMCII-MTP-0001 versión A

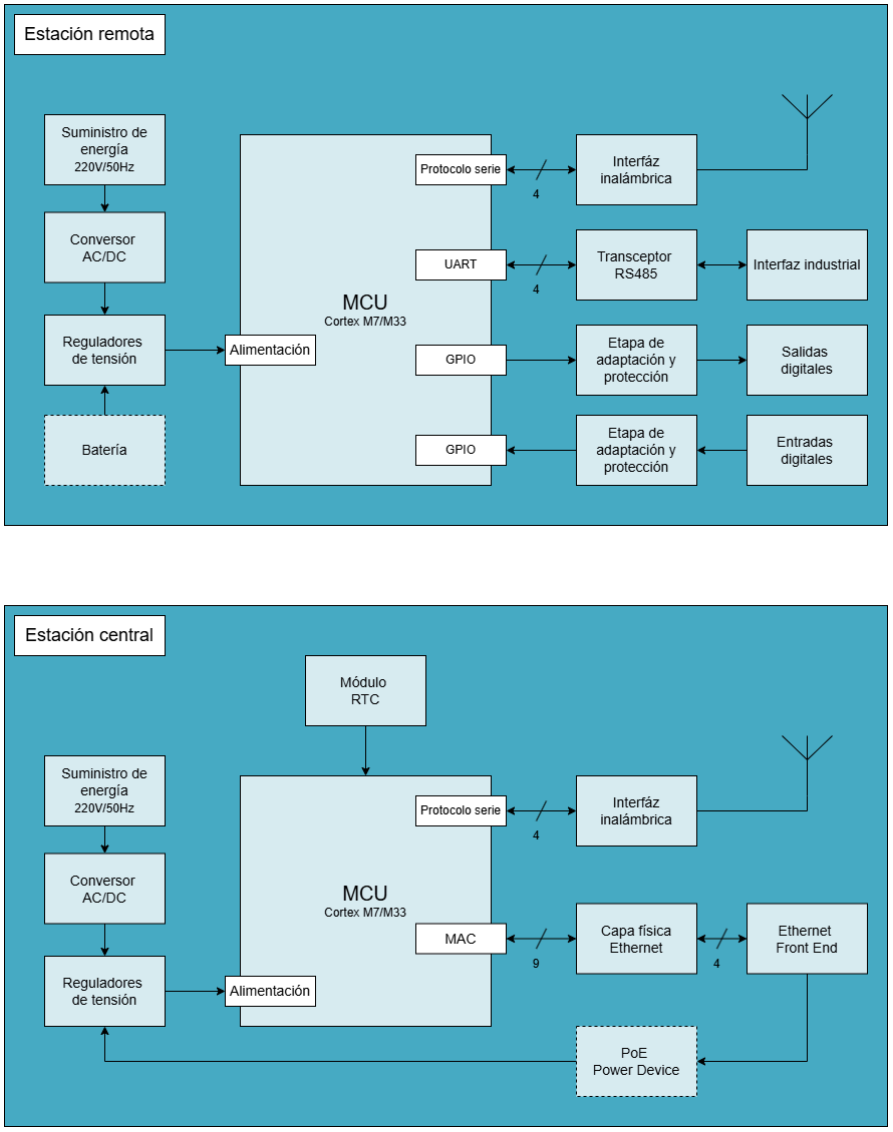
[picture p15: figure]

Figura 1. Diagrama en bloques del sistema.

SCMCII-MTP-0001 versión A

## 1.3. Contenidos del documento

El MTP incluye: Asignaciones, Bases del test, Estrategia general, Estrategia por nivel de
prueba, | Planificación, | Infraestructura, Organización, Entregables, Gestión de
configuración y Riesgos; siguiendo el índice recomendado del Apéndice E.

## 2. Asignaciones

## 2.1. Responsable

El responsable de la confección y mantenimiento de este Master Test Plan es Ing. Lucas Sebastián Kirschner, autor del Trabajo Final y a cargo del proyecto. Esta sección define “qué se prueba, quién y cuándo lo prueba”, brindando un marco común para las disciplinas involucradas.

## 2.2. Contratista

La asignación se ejecuta bajo responsabilidad del autor, quien asume el rol de Test Manager del proyecto académico.

## 2.3. Alcance

El alcance de este MTP cubre el software de:
- Estación central (stack de comunicaciones Ethernet, enlace inalámbrico con estaciones remotas, RTOS, servicios de red y gestión).
- Estaciones remotas (I/O industriales, comunicación serie robusta/RS-485 y enlace inalámbrico con la estación maestra).
- Capa de aplicación y API sobre una arquitectura en capas para separar controladores/IO/comunicaciones de la lógica de aplicación.
- Se excluye el detalle de validaciones mecánicas y certificaciones normativas (p.ej. ensayos ambientales), que serán considerados como supuestos externos del proyecto.

## 2.4. Objetivos

- Determinar si el sistema cumple los requerimientos definidos para central y remotas.
- Reportar las diferencias entre el comportamiento observado y el deseado.
- Entregar testware reutilizable para futuras iteraciones.

SCMCII-MTP-0001 versión A

## 2.5. Precondiciones

### 2.5.1. Externas

- Base de pruebas disponible: documentación técnica del sistema y de la arquitectura en capas según el Plan del Trabajo Final.
- Prototipos listos para ensayo: entrega de la estación central y al menos dos remotas para pruebas de aceptación e integración, de acuerdo al plan de proyecto.
- Hitos temporales académicos: la presentación pública del Trabajo Final está prevista para junio de 2026; las actividades de prueba deben planificarse para concluir antes de esa fecha.

### 2.5.2. Internas

TBD.

## 3. Bases del test

[1] L. S. Kirschner, “Plan de Trabajo Final – Sistema modular para monitoreo y control industrial con comunicación inalámbrica y capacidades de automatización embebida,” v5.0, 2025. [Online]. Available:
https://drive.google.com/file/d/1YOC7XgiZzi_qurarhp4CJc1SsLPuE3hN/view?usp=drive_link. Accessed: Oct. 20, 2025.
[2] IEEE Std 830-1998, “IEEE Recommended Practice for Software Requirements Specifications,”
IEEE | Computer | Society, | 1998. | [Online]. | Available:
https://drive.google.com/file/d/15OwKxACPtvC7gL5z7mI0iI1JXDSm9wkM/view?usp=drive_link. Accessed: Oct. 20, 2025.
[3] SCMCII-ER-0001-A, “Sistema modular para monitoreo y control industrial con comunicación inalámbrica y capacidades de automatización embebida – Especificación de requerimientos de
software.” | [Online]. | Available:
https://drive.google.com/file/d/1P7ljlgkc7BytAw4ma1Z8dHEHf2KU01g_/view?usp=drive_link. Accessed: Oct. 20, 2025.
[4] SCMCII-CU-0001-A, “Sistema modular para monitoreo y control industrial con comunicación inalámbrica y capacidades de automatización embebida – Casos de uso.” [Online]. Available: https://drive.google.com/file/d/1zcrfXkDYW7zmpCriQQtNuGMM71tlFQc7/view?usp=drive_link. Accessed: Oct. 20, 2025.
[5] SCMCII-AD-0001-A, “Sistema modular para monitoreo y control industrial con comunicación inalámbrica y capacidades de automatización embebida – Arquitectura y diseño detallado de
software.” | [Online]. | Available:
https://drive.google.com/file/d/18MnsaQgG8-j9Bs_qcZ3SidUqjazzYLOB/view?usp=drive_link. Accessed: Oct. 20, 2025.

SCMCII-MTP-0001 versión A

## 4. Estrategia general del test

## 4.1. Características de calidad

Se seleccionan y priorizan las siguientes características de calidad a ser testeadas y su importancia relativa:

Característica de calidad | Importancia relativa (%)
Funcionalidad | 30
Conectividad | 30
Confiabilidad | 20
Usabilidad | 15
Mantenibilidad | 5
Total | 100

Funcionalidad: el sistema deberá operar en ambientes industriales y controlar procesos críticos, por lo que la funcionalidad es central: debe cumplir sin desvíos la especificación de requerimientos (adquisición y actuación, coordinación central–remotas, alarmas y estados, modos de operación y enclavamientos de seguridad).
Conectividad: al ser un sistema distribuido, la comunicación entre estaciones es esencial: los enlaces cableados e inalámbricos deben ser estables, con latencia baja y variación controlada, y recuperarse solos ante cortes.
Confiabilidad: se espera operación continua con capacidad de tolerar fallas y recuperarse de forma segura ante caídas de tensión, pérdida de enlace o reinicios. Usabilidad: la interfaz y las funciones deben ser simples, claras y adaptables a distintos procesos productivos, con nombres coherentes, mensajes de error útiles y una guía breve para empezar.
Mantenibilidad: debe ser fácil actualizar y corregir el software sin efectos colaterales, gracias a un diseño por capas y componentes bien delimitados que eviten reintroducir fallas.
Dado que el sistema es distribuido y, por lo tanto, expone múltiples superficies de ataque, la seguridad se trata como una característica transversal que acompaña a conectividad y confiabilidad. Se verificará la integridad y autenticidad de mensajes, el aislamiento entre funciones y la protección de credenciales y llaves. Cuando el hardware lo permita, se

SCMCII-MTP-0001 versión A

aprovecharán módulos de seguridad por hardware disponibles en la plataforma elegida. Los ensayos incluirán intentos de acceso indebido, mensajes mal formados y verificación de que ante un evento de seguridad el sistema entra en un estado seguro y registrable.

## 4.2. Asignación de características a niveles de prueba

En la siguiente tabla se observan los niveles de prueba asignados a las distintas características de calidad detalladas en el punto anterior.
++: El testeo de la característica de calidad se realizará a fondo en este subsistema.
+: El testeo de la característica de calidad será cubierto en este subsistema.
- : La característica de calidad no representa un problema en este subsistema.
| Funcionalidad | Conectividad | Confiabilidad | Usabilidad | Mantenibilidad
Importancia relativa (%) | 30 | 30 | 20 | 15 | 5
Unitarias | + | + | - | - | +
Integración software | + | + | + | ++ | +
Integración software/ha rdware | + | ++ | + | + | -
Sistema | ++ | ++ | + | ++ | -
Campo | - | ++ | ++ | - | -

Funcionalidad: se presta especial atención a la funcionalidad del sistema como un todo Las integraciones previas se usan para asegurar que las piezas encajen, mientras que la aceptación confirma que no quedan desvíos respecto de los requisitos.
Conectividad: la verificación central es que las estaciones permanezcan comunicadas con entrega de mensajes alta, baja latencia y reconexión automática.
Confiabilidad: la prioridad es seguir operando y recuperarse de forma segura ante fallas. Usabilidad: se verifica que la interfaz sea clara y rápida de poner en marcha para un técnico: nombres coherentes, mensajes de error útiles y una guía breve que permita integrar y operar el sistema en poco tiempo. Las pruebas recorren tareas reales para detectar ambigüedades y pasos innecesarios.

SCMCII-MTP-0001 versión A

Mantenibilidad: el objetivo es poder cambiar y actualizar sin efectos colaterales. Se comprueba que las actualizaciones sean reproducibles, que exista un procedimiento para volver atrás y que los cambios demandan poco esfuerzo y bajo riesgo.

## 4.3. División del sistema en subsistemas

Los subsistemas que componen el sistemas y su importancia relativa son:

Subsistema | Importancia relativa (%)
Parte A: comunicación inalámbrica. | 30
Parte B: comunicación Ethernet/SCADA. | 5
Parte C: bus RS-485 industrial. | 20
Parte D: I/O en estaciones remotas. | 20
Parte E: coordinación central–remotas. | 20
Parte F: gestión de errores y alarmas. | 5
Total | 100

Descripción breve de subsistemas
Parte A – Comunicación inalámbrica. Mantener el enlace central–remotas con entrega de mensajes alta, latencia acotada y recuperación automática ante cortes o interferencias. Parte B – Comunicación Ethernet/SCADA. Intercambiar datos y órdenes con la red de planta y el sistema de supervisión con formatos y tiempos correctos.
Parte C – Bus RS-485 industrial. Direccionamiento, temporización, integridad de tramas y convivencia de múltiples nodos en cadena.
Parte D – I/O en estaciones remotas. Lectura confiable de entradas y actuación segura de salidas (rangos, tiempos, enclavamientos).
Parte E – Coordinación central–remotas. Orquestar medir–decidir–actuar, modos, estados y alarmas de todo el sistema.
Parte F – Gestión de errores y alarmas. Detección temprana de fallas, entrada a estado seguro, registro y notificación.

SCMCII-MTP-0001 versión A

Justificación de la importancia relativa
A (30%): mayor riesgo operativo y de desempeño; la comunicación inalámbrica sostiene el control distribuido.
C (20%) y D (20%): interacción directa con campo (bus industrial y E/S) donde aparecen la mayoría de desvíos funcionales.
E (20%): núcleo que encadena todas las funciones; errores aquí afectan todo el sistema. B (5%): interfaz necesaria con SCADA, pero con menor variabilidad en esta etapa.
F (5%): indispensable, aunque acotado en alcance inicial; se profundiza en campo y en iteraciones siguientes.

## 4.4. Determinación de la importancia relativa de los subsistemas

| Parte A | Parte B | Parte C | Parte D | Parte E | Parte F
Importanci a relativa (%) | 30 | 5 | 20 | 20 | 20 | 5
Unitarias | + | + | + | - | + | +
Integración software | + | + | + | + | + | +
Integración software/ha rdware | ++ | + | ++ | + | ++ | +
Sistema | ++ | + | + | ++ | ++ | ++
Campo | ++ | + | ++ | ++ | ++ | +

SCMCII-MTP-0001 versión A

## 4.5. Determinación de las técnicas de test a ser utilizadas

La siguiente tabla detalla la técnica de test aplicada para cada subsistema, siendo:
- State transition testing (STT)
- Control flow test (CFT)
- Elementary comparison test (ECT)
- Classification-tree method (CTM)
- Rare event testing (RET)
Técnica de test aplicada | Parte A | Parte B | Parte C | Parte D | Parte E | Parte F
STT | X | | X | X | X | X
CFT | | X | | | X | X
ECT | | X | X | X
CTM | | | | | X
RET | X | | | | | X

Se priorizan Transición de estados y Flujo de control.
Comparación elemental se aplica solo donde haya rangos/formatos claros (B, C, D). Árbol de clasificación se limita a un conjunto pequeño de combinaciones críticas (E). Eventos poco frecuentes se usan de forma puntual (A, F) para fallas raras pero relevantes.

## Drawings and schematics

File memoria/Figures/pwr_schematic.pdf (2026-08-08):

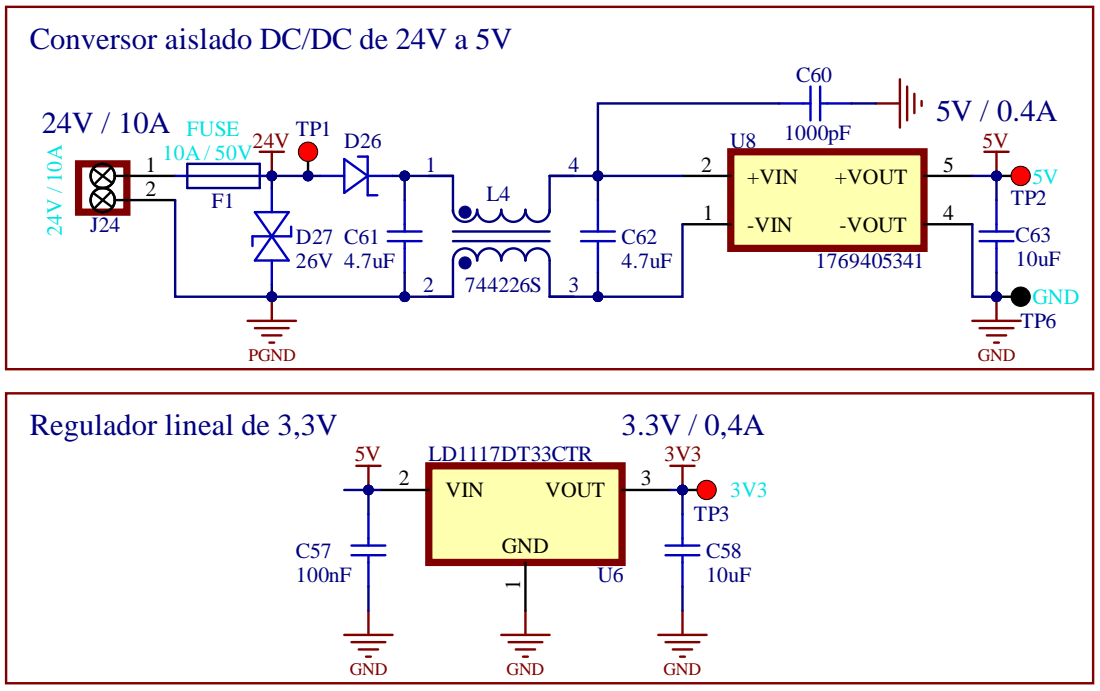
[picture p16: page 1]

Conversor aislado DC/DC de 24V a 5V

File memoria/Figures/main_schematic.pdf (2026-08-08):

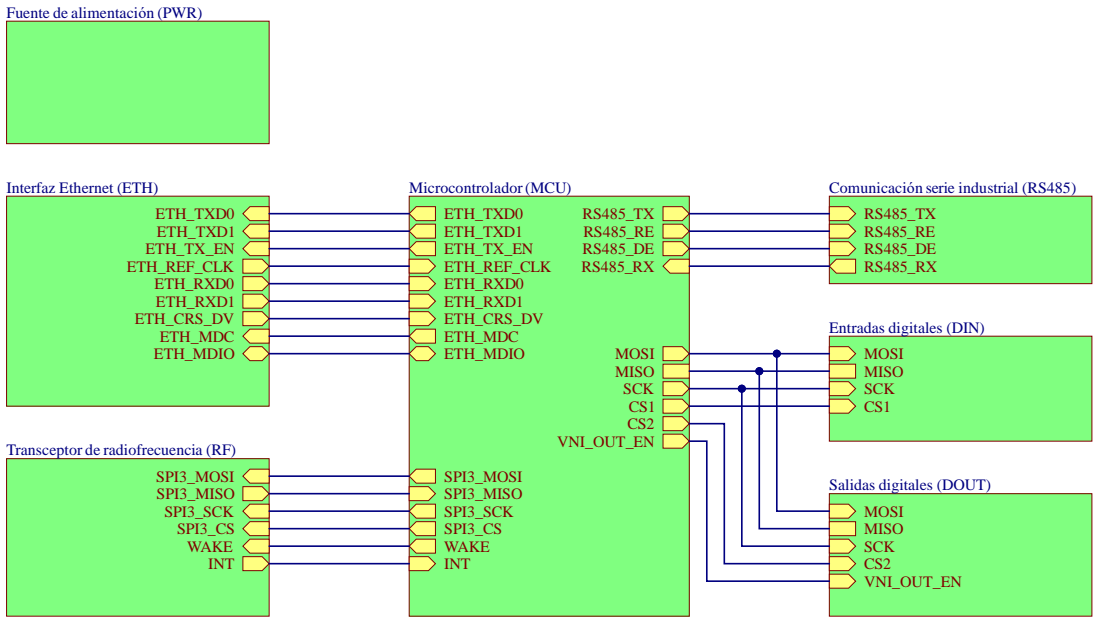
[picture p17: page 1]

Fuente de alimentación (PWR)

Transceptor de radiofrecuencia (RF)

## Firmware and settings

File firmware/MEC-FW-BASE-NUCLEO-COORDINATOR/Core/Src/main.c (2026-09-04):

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

/* Includes ------------------------------------------------------------------*/
#include "main.h"

/* USER CODE BEGIN Includes */
#include "mrf24j40.h"
#include "swo.h"
/* USER CODE END Includes */

/* USER CODE BEGIN PTD */

/**
 * @brief Logical network role assigned to the local MRF24J40 node.
 *
 * @details
 * This role selection determines which nonbeacon MAC configuration helper is
 * applied during task initialization.
 */
typedef enum
{
    MRF24J40_ROLE_DEVICE = 0,
    MRF24J40_ROLE_PAN_COORDINATOR
} mrf24j40_role_t;

/**
 * @brief Static configuration used to initialize the MRF24J40 task.
 *
 * @details
 * This structure contains the minimum configuration required by the task to
 * initialize the low-level driver and assign the local node identity within a
 * nonbeacon-enabled IEEE 802.15.4 network.
 */
typedef struct
{
    uint16_t pan_id;
    uint16_t short_address;
    mrf24j40_role_t role;
} mrf24j40_task_config_t;

/* USER CODE END PTD */

SPI_HandleTypeDef hspi3;
TIM_HandleTypeDef htim6;

/* USER CODE BEGIN PV */
static mrf24j40_packet_t tx_packet;
static mrf24j40_packet_t rx_packet;
static bool tx_flag;
static mrf24j40_task_config_t radio_cfg;
/* USER CODE END PV */

void SystemClock_Config(void);
static void MX_GPIO_Init(void);
static void MX_ICACHE_Init(void);
static void MX_SPI3_Init(void);
static void MX_TIM6_Init(void);

/* USER CODE BEGIN PFP */
static void app_init(void);
static void app_task(void);
static void app_build_test_frame(void);
static void app_print_frame(const char *prefix,
                            const uint8_t *frame,
                            uint8_t length);
/* USER CODE END PFP */

/**
  * @brief  The application entry point.
  * @retval int
  */
int main(void)
{
  /* MCU Configuration--------------------------------------------------------*/

  /* Reset of all peripherals, Initializes the Flash interface and the Systick. */
  HAL_Init();

  /* Configure the system clock */
  SystemClock_Config();

  /* Initialize all configured peripherals */
  MX_GPIO_Init();
  MX_ICACHE_Init();
  MX_SPI3_Init();
  MX_TIM6_Init();

  /* USER CODE BEGIN 2 */

  /* Para toggle del led amarillo */
  HAL_TIM_Base_Start_IT(&htim6);

  app_init();

  /* USER CODE END 2 */

  /* Infinite loop */
  /* USER CODE BEGIN WHILE */
  while (1)
  {
      app_task();

    /* USER CODE END WHILE */

    /* USER CODE BEGIN 3 */
  }
  /* USER CODE END 3 */
}

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
/* USER CODE BEGIN 4 */

static void app_print_frame(const char *prefix,
                            const uint8_t *frame,
                            uint8_t length)
{
    uint8_t i;

    printf("%s", prefix);

    for (i = 0u; i < length; i++)
    {
        printf("%02X", frame[i]);

        if (i < (length - 1u))
        {
            printf(" ");
        }
    }

    printf("\r\n");
}

static void app_init(void)
{
    radio_cfg.pan_id = 0x1234u;
    radio_cfg.short_address = 0x0001u;
    radio_cfg.role = MRF24J40_ROLE_PAN_COORDINATOR;

    (void)mrf24j40_init();

    if (radio_cfg.role == MRF24J40_ROLE_PAN_COORDINATOR)
    {
        (void)mrf24j40_configure_nonbeacon_pan_coordinator();
    }
    else
    {
        (void)mrf24j40_configure_nonbeacon_device();
    }

    (void)mrf24j40_set_pan_id(radio_cfg.pan_id);
    (void)mrf24j40_set_short_address(radio_cfg.short_address);
    (void)mrf24j40_set_extended_address();

    printf("[RADIO] COORDINATOR READY - PAN: 0x%04X - ADDR: 0x%04X\r\n",
           radio_cfg.pan_id,
           radio_cfg.short_address);
}

static void app_task(void)
{
    mrf24j40_status_t status;
    bool tx_complete;

    /* Verifica interrupciones pendientes */
    (void)mrf24j40_update_interrupt_flags();

    /* Si hay mensaje pendiente, lo lee y procesa */
    status = mrf24j40_read_rx_fifo(&rx_packet);

    if (status == MRF24J40_OK)
    {
        printf("[RADIO] RX LENGTH: %u\r\n",
               (unsigned int)rx_packet.frame_length);

        printf("[RADIO] RX: %02X %02X %02X %02X %02X %02X "
               "%02X %02X %02X %02X %02X %02X\r\n",
               rx_packet.frame[0],
               rx_packet.frame[1],
               rx_packet.frame[2],
               rx_packet.frame[3],
               rx_packet.frame[4],
               rx_packet.frame[5],
               rx_packet.frame[6],
               rx_packet.frame[7],
               rx_packet.frame[8],
               rx_packet.frame[9],
               rx_packet.frame[10],
               rx_packet.frame[11]);

        __NOP();
    }

    /* Verifica si se debe transmitir un paquete */
    if (tx_flag == 1u)
    {
        /* Deshabilita bandera de transmision */
        tx_flag = 0u;

        /* Arma el paquete a transmitir */
        app_build_test_frame();

        app_print_frame("[RADIO] TX: ",
                        tx_packet.frame,
                        tx_packet.frame_length);

        /* Transmite paquete con ACK deshabilitado */
        (void)mrf24j40_write_tx_normal_fifo(&tx_packet, false);
    }

    /* Espera confirmación de transmision */
    status = mrf24j40_get_tx_complete(&tx_complete);

    if ((status == MRF24J40_OK) && (tx_complete == true))
    {
        printf("[RADIO] TX COMPLETE\r\n");
    }
}

static void app_build_test_frame(void)
{
    tx_packet.frame[0] = 0x41u;
    tx_packet.frame[1] = 0x88u;
    tx_packet.frame[2] = 0x01u;
    tx_packet.frame[3] = 0x34u;
    tx_packet.frame[4] = 0x12u;
    tx_packet.frame[5] = 0x01u;
    tx_packet.frame[6] = 0x00u;
    tx_packet.frame[7] = 0x02u;
    tx_packet.frame[8] = 0x00u;
    tx_packet.frame[9]  = 0x01u;
    tx_packet.frame[10] = 0x02u;
    tx_packet.frame[11] = 0x03u;
    tx_packet.frame_length = 12;
}

void HAL_GPIO_EXTI_Falling_Callback(uint16_t GPIO_Pin)
{
    if (GPIO_Pin == INT_Pin)
    {
        mrf24j40_set_interrupt_pending();

        printf("[RADIO] IRQ\r\n");
    }
}

void HAL_GPIO_EXTI_Rising_Callback(uint16_t GPIO_Pin)
{
    if (GPIO_Pin == USER_BUTTON_Pin)
    {
        HAL_GPIO_TogglePin(GR_LED_GPIO_Port, GR_LED_Pin);

        tx_flag = 1u;
    }
}

void HAL_TIM_PeriodElapsedCallback(TIM_HandleTypeDef *htim)
{
    if(htim->Instance == TIM6)
    {
        HAL_GPIO_TogglePin(YE_LED_GPIO_Port, YE_LED_Pin);
    }
}

/* USER CODE END 4 */
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


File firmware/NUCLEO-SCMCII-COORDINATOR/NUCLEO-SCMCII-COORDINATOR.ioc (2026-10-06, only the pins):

Mcu.UserName=STM32H563ZITx
PA0.GPIO_Label=INT
PA0.Signal=GPXTI0
PA13(JTMS/SWDIO).Signal=DEBUG_JTMS-SWDIO
PA14(JTCK/SWCLK).Signal=DEBUG_JTCK-SWCLK
PA15(JTDI).GPIO_Label=SPI3_CS
PA15(JTDI).Signal=GPIO_Output
PA3.GPIO_Label=TP1
PA3.Signal=GPIO_Output
PA5.Signal=SPI1_SCK
PB3(JTDO/TRACESWO).Signal=DEBUG_JTDO-SWO
PB5.Signal=SPI1_MOSI
PC10.Signal=SPI3_SCK
PC11.Signal=SPI3_MISO
PC12.Signal=SPI3_MOSI
PD14.GPIO_Label=SPI1_CS_VNI
PD14.Signal=GPIO_Output
PD15.GPIO_Label=SPI1_CS_CLT
PD15.Signal=GPIO_Output
PD2.GPIO_Label=WAKE
PD2.Signal=GPIO_Output
PE9.GPIO_Label=OUT_EN
PE9.Signal=GPIO_Output
PF6.GPIO_Label=RS485_RO
PF6.Signal=UART7_RX
PF7.GPIO_Label=RS485_DI
PF7.Signal=UART7_TX
PF8.GPIO_Label=RS485_DE
PF8.Signal=GPIO_Output
PF9.GPIO_Label=RS485_RE
PF9.Signal=GPIO_Output
PG12.GPIO_Label=RESET
PG12.Signal=GPIO_Output
PG9.Signal=SPI1_MISO

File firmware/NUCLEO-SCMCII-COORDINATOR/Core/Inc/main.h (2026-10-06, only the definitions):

#define RS485_RO_Pin GPIO_PIN_6
#define RS485_RO_GPIO_Port GPIOF
#define RS485_DI_Pin GPIO_PIN_7
#define RS485_DI_GPIO_Port GPIOF
#define RS485_DE_Pin GPIO_PIN_8
#define RS485_DE_GPIO_Port GPIOF
#define RS485_RE_Pin GPIO_PIN_9
#define RS485_RE_GPIO_Port GPIOF
#define INT_Pin GPIO_PIN_0
#define INT_GPIO_Port GPIOA
#define INT_EXTI_IRQn EXTI0_IRQn
#define TP1_Pin GPIO_PIN_3
#define TP1_GPIO_Port GPIOA
#define OUT_EN_Pin GPIO_PIN_9
#define OUT_EN_GPIO_Port GPIOE
#define SPI1_CS_VNI_Pin GPIO_PIN_14
#define SPI1_CS_VNI_GPIO_Port GPIOD
#define SPI1_CS_CLT_Pin GPIO_PIN_15
#define SPI1_CS_CLT_GPIO_Port GPIOD
#define SPI3_CS_Pin GPIO_PIN_15
#define SPI3_CS_GPIO_Port GPIOA
#define WAKE_Pin GPIO_PIN_2
#define WAKE_GPIO_Port GPIOD
#define RESET_Pin GPIO_PIN_12
#define RESET_GPIO_Port GPIOG

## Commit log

2025-09-12 Se corrige .gitignore para excluir archivos temporales de altium
2025-09-29 Se agregan manuales y hojas de datos
    [CIAA-NXP Bill of Materials.xls]
2025-12-22 Primera versión revisada de esquemáticos. Se agrega documentación. Se comienza desarrollo del PCB.
    [Block diagram.SchDoc, CIAA-NXP Bill of Materials.xls, Digital Input (DIN).SchDoc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]
2026-02-11 Se agregan avances en el ruteo del PCB
    [Digital Input (DIN).SchDoc, Digital Output (DOUT).SchDoc, Ethernet Interface (ETH).SchDoc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]
2026-03-20 Se agrega PCB MEC-V1.0 RevB
    [Digital Input (DIN).SchDoc, Digital Output (DOUT).SchDoc, Ethernet Interface (ETH).SchDoc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]
2026-03-28 Se agrega PCB MEC-V1.0 RevD - Enviado a fabricar a JLCPCB
    [Digital Input (DIN).SchDoc, Ethernet Interface (ETH).SchDoc, Industrial Serial Comm (RS485).SchDoc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]
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2026-04-12 Se agrega primera revision de firmware: comunicación básica unidireccional entre dos nodos mrf24j40
2026-04-12 refactor: incorporación de manejo de errores estructurado en driver MRF24J40
    [main.c, mrf24j40.c]
2026-04-30 Se agregan drivers de SN65HVD82, SCLT3-8BT8 y VNI8200XP-32. Se sube proyecto con pinout del STM32H563RI de la MEC V1.0.
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2026-05-11 Se agrega primera versión de la memoria para TTFA, Resumen y Capítulo 1 (Nv TI_Kirschner_Lucas_V1.pdf)
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2026-05-18 Se agrega segunda versión de la memoria para TTFA, Capítulo 2 (Nv TI_Kirschner_Lucas_V2.pdf)
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2026-06-08 Se agregan programas simples en bare metal y freertos de prueba de recepción del módulo MRF24J40
2026-06-10 Se actualiza MEC-FW-RTOS-NUCLEO-COORDINATOR con las modificaciones que funcionaron en MC-FW-RTOS-MRF24J40. Inicializa correctamente el mrf24j40 y recibe interrupción por recepción de trama.
    [main.c, main.h, mrf24j40.c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]
2026-06-16 Se agrega tarea de usuario para consumo de cola de recepción de radio
2026-06-18 Se agregan tareas para manejo de entradas (dinTask) y salidas (doutTask) y se modifica userTask para pruebas
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2026-06-19 Se corrige formato de rtos_stats
2026-06-19 Se agrega verificación de correcta creación de recursos de FreeRTOS
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2026-07-09 Se agrega nueva versión de TI_Kirschner_Lucas_V1.pdf con correcciones del segundo curso TTFA
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2026-07-21 Se agrega comienzo (1/3) del Cap 3 de la memoria y correcciones del Cap 2
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2026-08-06 Se agrega programa básico de validación de RS485 que realiza Echo desde el uC a la PC
2026-08-06 Se cambia programa base de RS485 de transmisión bloqueante a transmisión por interrupción
    [putty_config.txt]
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2026-08-14 Se agrega el repositorio workspace auxiliar de trabajo
    [putty_config.txt]
2026-08-15 Se agregan programas de test de la MEC V1.0 de VNI8200XP32 (no funciona) y MRF24J40 (si funciona)
    [putty_config.txt]
2026-08-15 Se corrige workspace auxiliar de pruebas
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2026-08-18 Se agrega V6 de la memoria. Se comienza a escribir el Cap 4.
2026-08-20 Se agregan correcciones al Cap 3 de la V6. Aprobados Cap 1, 2 y 3 correspondientes a TTFA.
2026-08-22 Se agregan avances en el Cap 4 de la memoria: Ensayos de entradas digitales
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2026-08-29 Se agrega ensayo de RS485 a Cap 4
    [realterm_config.txt]
2026-09-04 Se finaliza sección de Ensayos de Hardware - se agrega ensayos de comunicación inalámbrica.
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2026-09-22 se agrega NUCLEO-SCMCII-COORDINATOR Y MEC-SCMCII-COORDINATOR. Se observa correcto funcionamiento de la comunicación inalámbrica en la MEC
    [MEC-SCMCII-COORDINATOR.ioc, NUCLEO-SCMCII-COORDINATOR.ioc, NUCLEO-SCMCII-SLAVE.ioc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]
2026-09-26 test(sclt38bt8): incorpora Ceedling e inicia pruebas unitarias del módulo de entradas
    Se incorpora Ceedling como entorno de pruebas unitarias del firmware, utilizando Unity y CMock para ejecutar las pruebas sobre el host y aislar las dependencias de hardware mediante mocks. Se configu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
    Como primera validación se inicia la cobertura unitaria del controlador SCLT3-8BT8 utilizado para la adquisición de las entradas digitales. Se agrega una prueba sobre sclt38bt8_read_inputs() que veri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
2026-09-26 test(sclt38bt8): agrega pruebas unitarias del controlador de entradas
    Se incorporan pruebas unitarias para el controlador SCLT3-8BT8 utilizando Ceedling, Unity y CMock, aislando la dependencia de la capa io_port mediante callbacks simulados. Los ensayos verifican la interfaz pública sclt38bt8_read_inputs() y los principales caminos de ejecución del controlador.
    Se comprueba el manejo de punteros nulos y errores provenientes de la capa de acceso, la recepción y decodificación de una trama válida, y la detección de pérdida de alimentación, bits de parada inválidos, errores de paridad, subtensión y sobretemperatura. Las tramas simuladas respetan el formato y los bits de paridad defin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
2026-09-26 test(vni8200xp32): agrega pruebas unitarias del controlador de salidas
    Se incorporan pruebas unitarias para el controlador VNI8200XP-32 utilizando Ceedling, Unity y CMock, aislando la dependencia de la capa io_port mediante callbacks simulados. Los ensayos verifican la interfaz pública vni8200xp32_write_outputs() y los principales caminos de ejecución del controlador.
    Se comprueba el manejo de errores provenientes de la capa de acceso, la generación de una trama de comando válida y el procesamiento de la respuesta del dispositivo. También se valida la detección de errores de paridad en la trama recibida, fallas de comunicación SPI, condiciones anómalas de realimentación del convert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
2026-09-26 test(rs485): agrega pruebas unitarias del controlador de comunicación
    Se incorporan pruebas unitarias para el controlador RS485 utilizando Ceedling, Unity y CMock, aislando la dependencia de la capa rs485_port mediante funciones simuladas. Los ensayos verifican las principales operaciones de la interfaz pública y las transiciones de estado asociadas al funcionamiento asíncrono del controlador.
    Se comprueba la inicialización y reinicialización, el inicio y exclusión mutua de operaciones de transmisión y recepción, la recuperación del dato recibido, el rechazo de nuevas operaciones ante estados incompatibles y la cancelación de transferencias activas. También se valida el procesami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
2026-09-26 test(mrf24j40): agrega pruebas unitarias del controlador de radio
    Se incorporan pruebas unitarias para el controlador MRF24J40 utilizando Ceedling, Unity y CMock, aislando la dependencia de la capa mrf24j40_port mediante funciones simuladas. Los ensayos verifican l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
    Se comprueba la inicialización del dispositivo, la configuración como coordinador PAN y dispositivo, la escritura del PAN ID y de la dirección corta, y el procesamiento de eventos de interrupción. Ta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
2026-10-02 test(dout): agrega medición temporal del procesamiento de salidas digitales
    Se incorpora una prueba de temporización para evaluar el tiempo de ejecución de la actualización de las salidas digitales mediante el controlador VNI8200XP-32.
    La tarea de aplicación genera 1000 solicitudes consecutivas de actualización, alternando los patrones 0x00 y 0xFF, mientras que app_dout mide mediante el contador de ciclos DWT el tiempo empleado por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
    La prueba registra la cantidad de operaciones válidas y erróneas y calcula los tiempos mínimo, promedio y máximo en ciclos de CPU. Con el sistema operando a 50 MHz se obtuvo un tiempo medio de aproxi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
2026-10-06 test(din): agrega medición temporal de la adquisición de entradas digitales
    Se incorpora una prueba de temporización para evaluar el tiempo de ejecución de la adquisición de las entradas digitales mediante el controlador SCLT3-8BT8.
    La tarea app_din registra 1000 adquisiciones consecutivas y mide mediante el contador de ciclos DWT el tiempo empleado por sclt38bt8_read_inputs(), excluyendo de la medición la actualización de la im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
    La prueba registra la cantidad de operaciones válidas y erróneas y calcula los tiempos mínimo, promedio y máximo en ciclos de CPU. Con el sistema operando a 50 MHz se obtuvo un tiem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
2026-10-06 test(radio): agrega instrumentación para medir tiempos de propagación
    Se incorpora en NUCLEO-SCMCII-COORDINATOR y NUCLEO-SCMCII-SLAVE la instrumentación necesaria para realizar la medición del tiempo de propagación de la comunicación inalámbrica mediante osciloscopio.
    La prueba utiliza la salida TP1, correspondiente al GPIO PA3 del NUCLEO-H563ZI y disponible en el pin 43 del conector CN10. En el nodo transmisor se conmuta esta salida inmediatamente antes de iniciar la transmisión mediante el MRF24J40, mientras que en el coordinador se conmuta al recibir y validar correctamente la trama.
    La diferencia temporal entre los flancos generados en ambos dispositivos permitirá determinar m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
    [NUCLEO-SCMCII-COORDINATOR.ioc, NUCLEO-SCMCII-SLAVE.ioc, main.c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]
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2026-10-26 test(integration): valida comunicación bidireccional y control remoto de salidas
    Se realizaron pruebas de integración entre los proyectos MEC-SCMCII-COORDINATOR (MEC-V1.0) y NUCLEO-SCMCII-SLAVE (NUCLEO-H563 con NUCLEO-PLC01), utilizando comunicación inalámbrica IEEE 802.15.4 mediante MRF24J40.
    Correcciones realizadas:
    - Se corrigió en el Coordinator la dirección del Device de 0x0002 a 0x0001.
    - Se deshabilitaron las pruebas temporales de entradas y salidas digitales en el Slave para permitir el funcionamiento normal de los servicios durante los ensayos de integración.
    Pruebas realizadas:
    - Inicialización y configuración correcta de ambos transceptores con PAN ID 0x1234.
    - Transmis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
2026-10-28 docs(chapter4): actualiza ensayos de integración y corrige V7 del informe
    Se avanza en la validación funcional del sistema y se actualiza el capítulo 4 de la memoria, incorporando los resultados de las pruebas de integración y el análisis general de los ensayos realizados.
    Se documentan las siguientes pruebas de integración:
    - Adquisición y reporte inalámbrico de los ocho canales de entradas digitales desde la estación remota hacia la central.
    - Control remoto de las ocho salidas industriales mediante comandos IEEE 802.15.4.
    - Detección de transmisiones sin reconocimiento ACK durante la desconexión de la estación remota.
    - Recuperación de la comunicación inalámbrica tras rest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
2026-11-03 docs(memoria): incorpora correcciones de revisión V9 y optimiza distribución del contenido
    Se actualiza la memoria del Trabajo Final a la versión V9, incorporando las observaciones recibidas durante la revisión de la versión anterior.
    Se realizan los siguientes ajustes:
    - Se corrigen aspectos de redacción y presentación en los capítulos 4 y 5.
    - Se optimiza la distribución del contenido en los capítulos 1 y 3 para reducir espacios en blanco.
    - Se ajusta puntualmente la extensión de algunos párrafos, manteniendo la coherencia y el contenido técnico original.
    - Se revisa la ubicación de figuras y tablas para mejorar la continuidad del texto y evitar interrupciones innecesarias.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
2026-11-06 docs(memoria): incorpora correcciones finales de revisión V10
    Se actualiza la memoria del Trabajo Final a la versión V10, incorporando las observaciones realizadas sobre la versión V9.
    Se reemplaza el término «proyecto» por «trabajo» en las secciones señaladas, con el objetivo de mantener la uniformidad terminológica y adecuar la redacción al contexto académico del documento.
    Se corrige también la referencia de la sección 2.2.7, correspondiente a los kits de desarrollo y evaluación, en relación con la observación realizada sobre la sección 2.2.6.
    Se actualiza el PDF de la memoria y se incorpora el archivo de comparación respecto de la versión anterior, manteniendo sin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

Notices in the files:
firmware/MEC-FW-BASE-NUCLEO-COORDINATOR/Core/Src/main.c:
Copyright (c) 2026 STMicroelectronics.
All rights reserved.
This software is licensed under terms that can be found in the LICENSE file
